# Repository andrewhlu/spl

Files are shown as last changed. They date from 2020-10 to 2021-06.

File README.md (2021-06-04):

<div class="center">
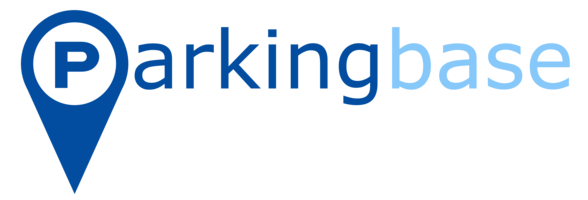
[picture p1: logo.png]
    
</div>

# Smart Parking Lot

A project for [ECE 189 - Computer Engineering Capstone](https://web.ece.ucsb.edu/~yoga/capstone/) led by Professor Isukapalli at UC Santa Barbara

---

[Parkingbase Demo Video](https://www.youtube.com/watch?v=abxjF7t0qpM)

[Parkingbase Poster](docs/poster.pdf)

---

## Team Members

* Andrew Lu
* Finn Linderman
* Luyao Han
* Seungjun Cho

## The Problem

Drivers spend too much time in parking lots trying to find an open space to park in. Many parking lots only have per-floor capacity indicators, and existing solutions are prohibitively expensive.

What if we could utilize low-cost sensors and a companion application to navigate drivers to empty parking spots faster, at a low cost to facility owners?

## Project Overview

**The goal of this project is to design a smart parking lot that will direct drivers to the nearest open parking space in an efficient, accurate, and clean manner.**

We accomplish this using:

* Small, inexpensive parking lot sensors with long-range and low-power transmission
* Modern, open-source, and cloud-based software solutions
* Easy-to-use mobile interfaces

# Technical Details

For a more detailed description, please take a look at our [project presentation slides](docs/final-presentation.pdf).

## System Overview

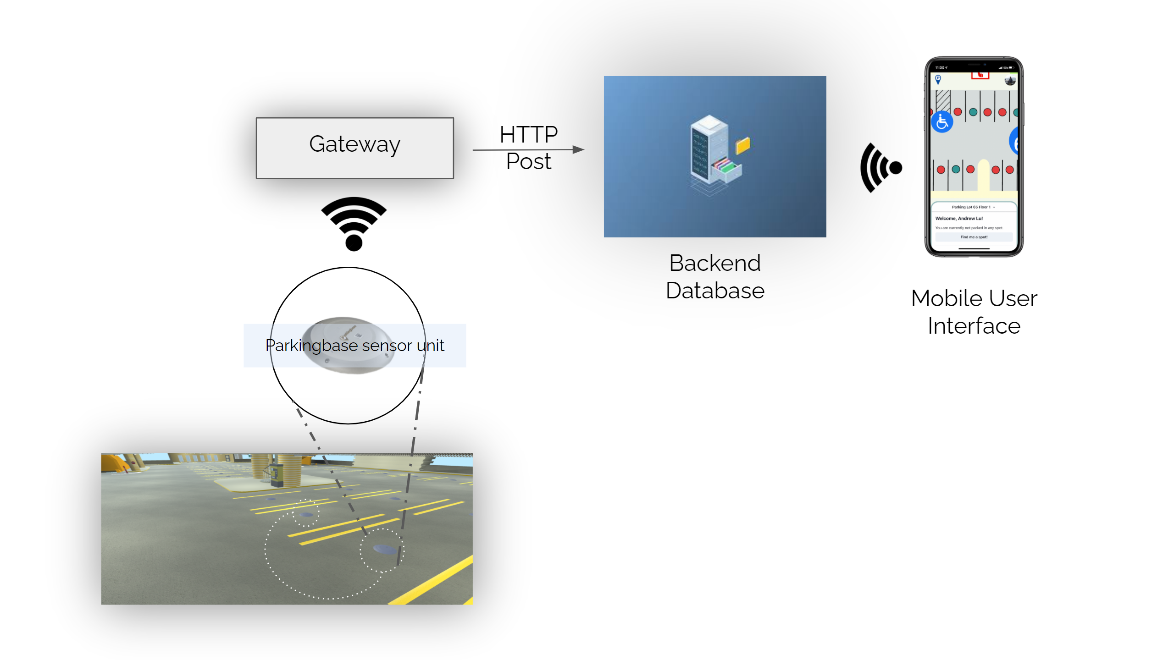
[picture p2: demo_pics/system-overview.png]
System Overview


## Application Scene

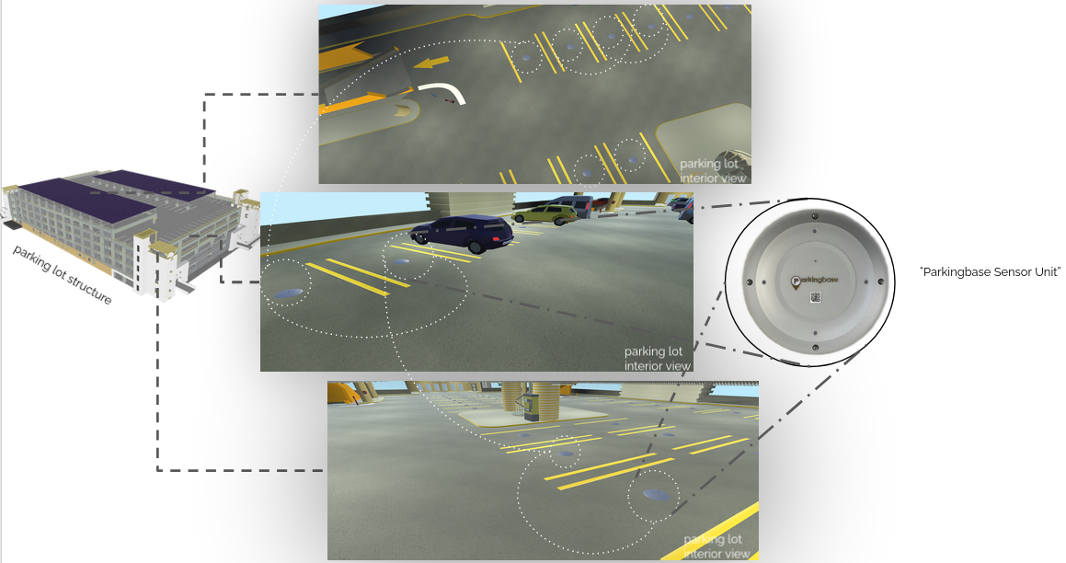
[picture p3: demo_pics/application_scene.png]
Application Scene


## Block Diagram

<div class="center">
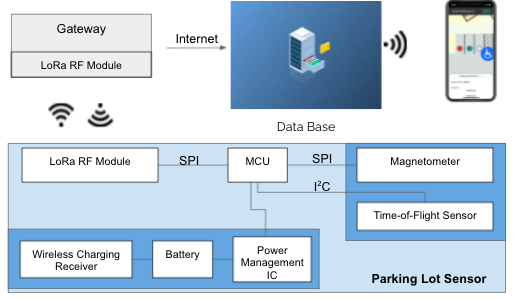
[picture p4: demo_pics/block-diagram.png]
  
</div>

## Sensor Unit Assembly

<div class="center">
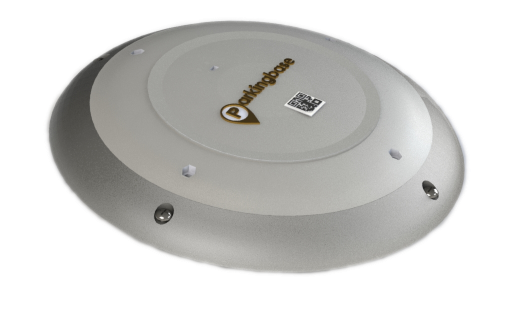
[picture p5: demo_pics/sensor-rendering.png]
  
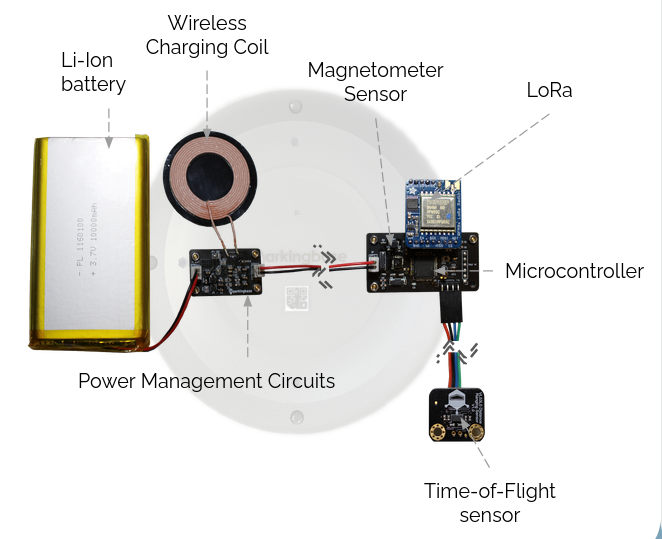
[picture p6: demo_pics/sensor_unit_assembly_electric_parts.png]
  
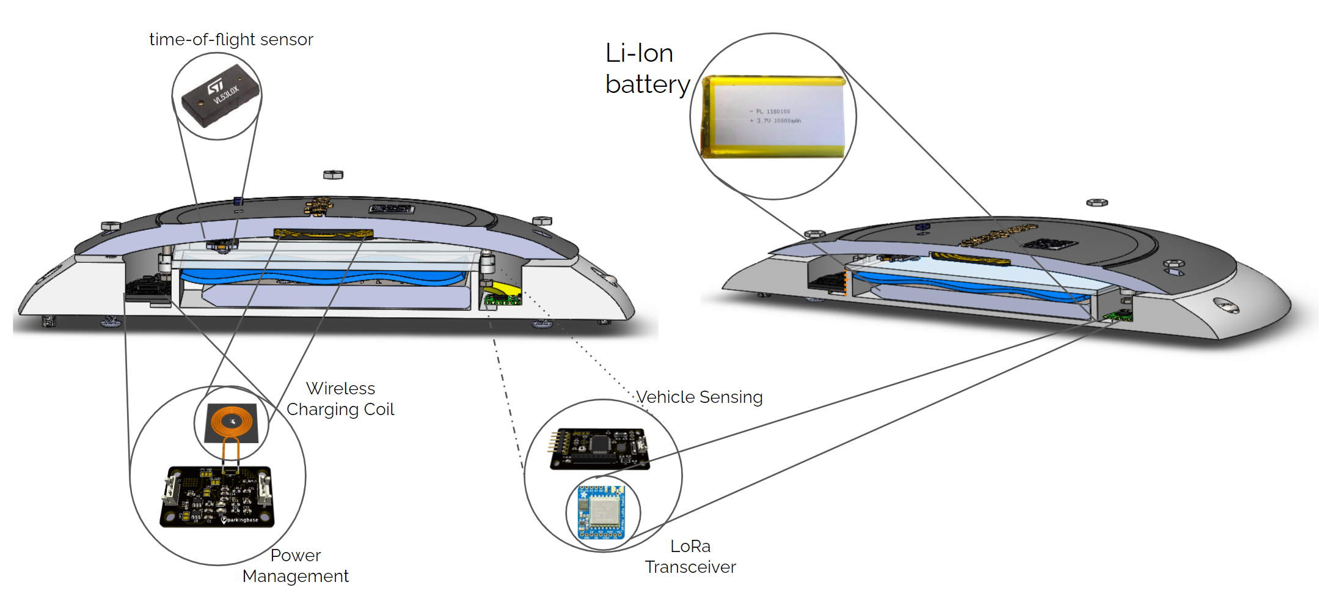
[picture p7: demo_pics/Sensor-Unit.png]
  
</div>

## Firmware Block Diagram

<div class="center">
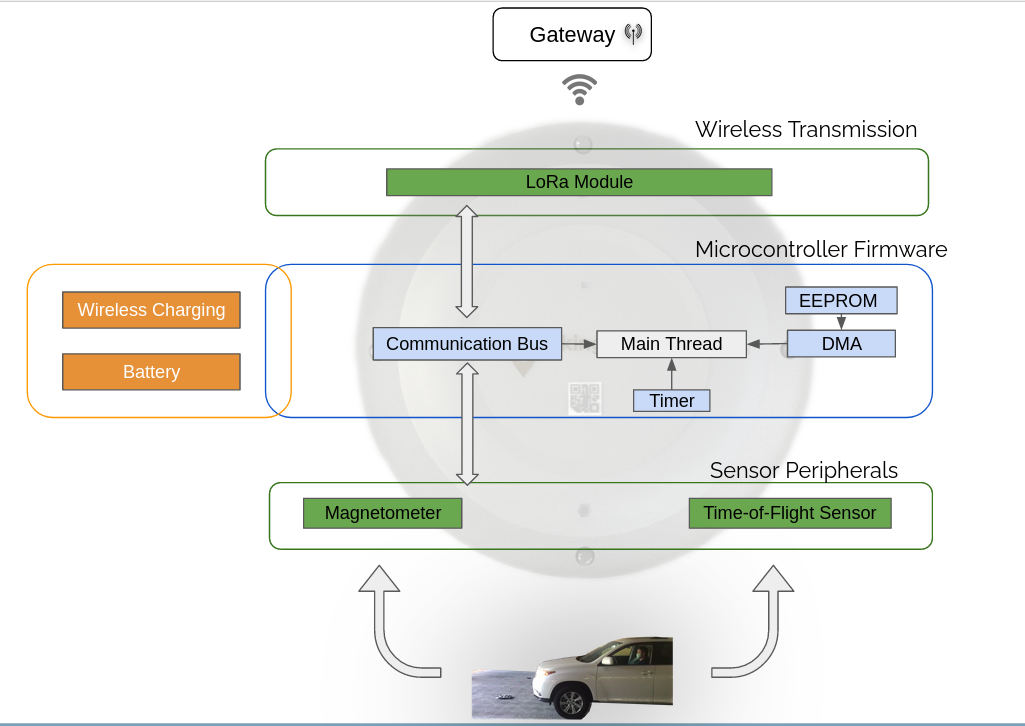
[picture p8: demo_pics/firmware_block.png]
  
</div>

## Sensor Unit PCB Design

The raw Kicad design files can be found in the [pcb-design folder](https://github.com/andrewhlu/spl/tree/main/pcb_design) in our repo.

[PCB Schematic (as PDF)](docs/sch.pdf)

[PCB Schematic (as PNG Image)](docs/sch.png)

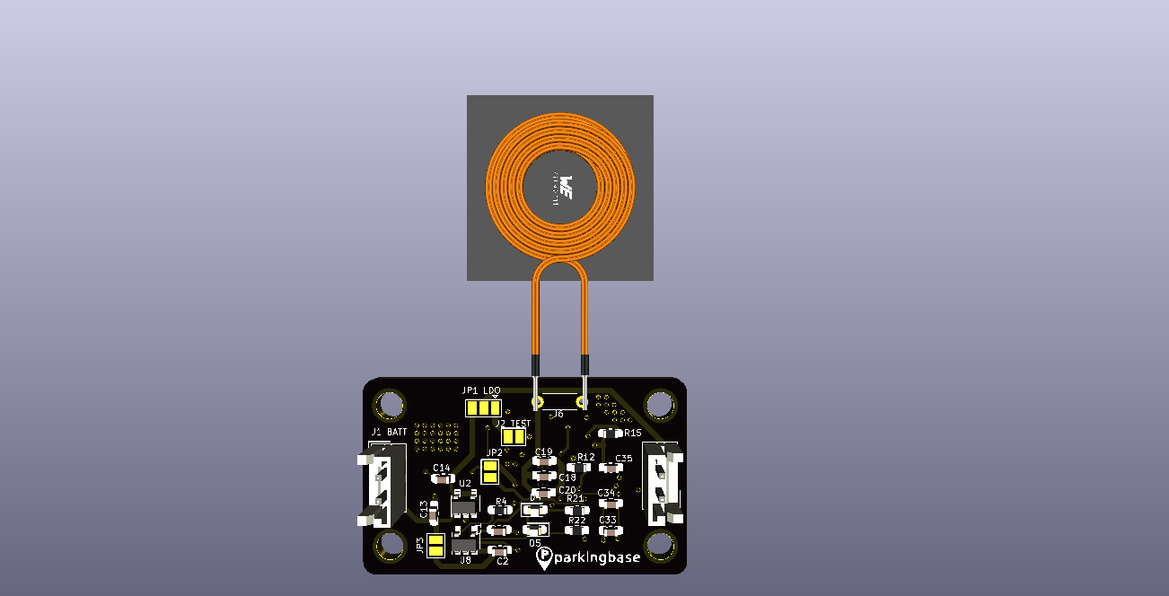
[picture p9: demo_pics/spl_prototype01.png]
Prototype


## GUI Screenshots

Driver User Interface:

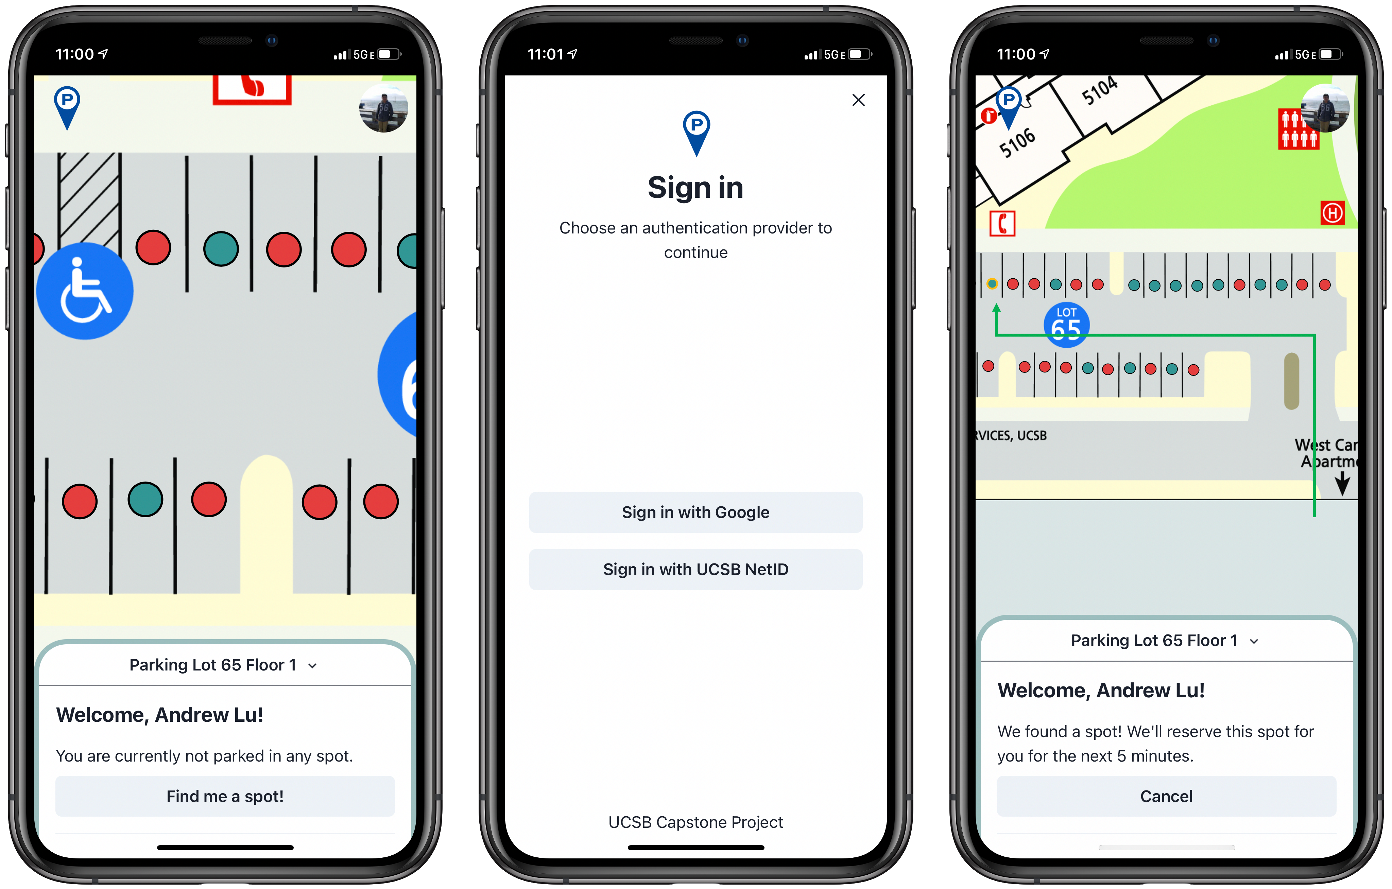
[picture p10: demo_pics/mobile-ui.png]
Mobile UI


Editor User Interface:

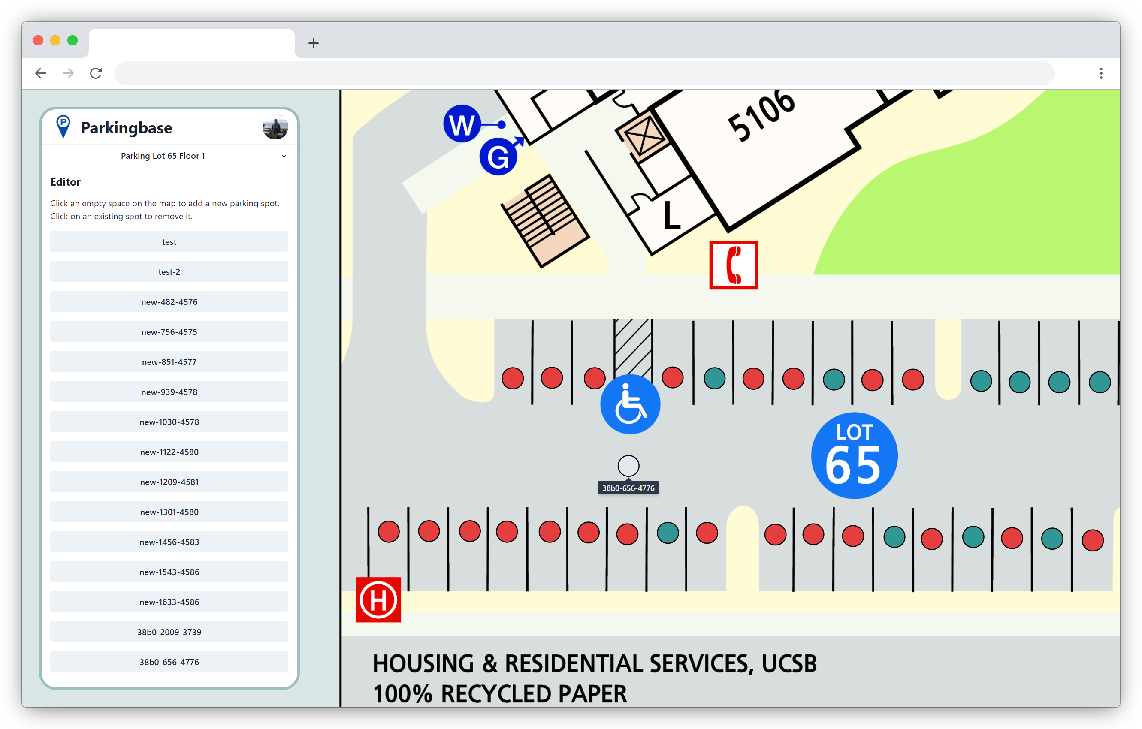
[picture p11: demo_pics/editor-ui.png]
Editor UI


## Code Repositories

* [spl](https://github.com/andrewhlu/spl)
  * Documentation for this website
  * PCB Design files
  * Demo pictures
* [spl-web](https://github.com/andrewhlu/spl-web)
  * Code for our website, including the React frontend and backend API routes
* [parkingbase-auth](https://github.com/andrewhlu/parkingbase-auth)
  * Code for our custom authentication server

# Project Progress Updates

[Initial Design](docs/initial-design.pdf)

[Milestone 1](docs/milestone1.pdf)

[Milestone 2](docs/milestone2.pdf)

[Fall Quarter Review Presentation](docs/fall-quarter-review.pdf)

[Winter Quarter Review Presentation](docs/winter-quarter-review.pdf)

[Final Poster](docs/poster.pdf)

[Final Presentation](docs/final-presentation.pdf)

<!-- Custom CSS for GitHub Pages -->

<style>
  .markdown-body h1:first-of-type {
    display: none;
  }

  .center {
    text-align: center;
    padding: 1rem;
  }
</style>

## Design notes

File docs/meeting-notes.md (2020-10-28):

# Smart Parking Lot - Team Meeting Notes

## 10/5 Meeting

We started this meeting by deciding on our team lead - Andrew Lu. 

We also decided on a scribe for our meetings - Kelly Yeh.

Resources compiled from individual research:

* [Bosch Parking Lot Sensor](https://www.bosch-connectivity.com/products/connected-mobility/parking-lot-sensor/)
  * A solution very similar (at least in appearance) to the one seen on JAPA. 
  * [Bosch Datasheet, Manuals](https://www.bosch-connectivity.com/products/connected-mobility/parking-lot-sensor/downloads/)
  * [Alliot (Vendor) Datasheet, Specs](https://www.alliot.co.uk/products/sensors/parking-management-sensors/bosch-lorawan-parking-sensor/)
    * This vendor sells for [£175.75 + VAT](https://www.alliot.co.uk/products/sensors/parking-management-sensors/bosch-lorawan-parking-sensor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) (which is roughly $227.2 excluding tax).
    * This is about 7.6% of our budget, so we don't think it's worth the investment to purchase for R&D.
* [2008 IEEE Paper from USC - "Intelligent Parling Lot Applications Using Wireless Sensor Networks"](http://anrg.usc.edu/~amitabhag/papers/CTS-2008.pdf)
* [Vehicle Detection Solutions - YouTube](https://www.youtube.com/watch?v=7a1fiUJtp_k)

Brief notes from our discussion of the various sensors:

Ultrasonic Sensor
- Generally very accurate when used to detect vehicles 
- Tradeoff between accuracy and power

Magnetometer
- Relatively low power consumption
- Complicated object detection algorithm
- May require heavy signal processing
- More resistant to noise

IR light
- Requires emitter + sensor combo (something on both sides)
- Measure light being emitted
- Can be used at night, but costly, and can only be used indoors

Action Items: 
- Clarify with Yoga regarding power consumption and usage/maintenance requirements in Parking lot 10 and which parking lots the project will be used for.
- Decide on overhead wired vs in-ground vehicle detection sensor
- Research and decide if solar power is an option

## 10/7 Meeting

Office hours with Yoga, Luyao, Andrew

Confirmed with Yoga: 
- wired devices are not accepted in parking lot
- cannot get a Park JAPA sensor from TPS

Suggested research topics:
- wireless transceiver device suited for average parking lot dimension
- low power consumption processor
  - Luyao will look into STM32L0
- solar panels as a method of extending battery life

Suggested device aspects:
- should last for at least 5 years

## 10/9 Meeting

We started by discussing our new project requirements from Office Hours

Problems with Battery-powered Solutions
- Wireless communication
  - This might require a lot of power, esp. to get past metal from cars and concrete slabs

Problems with Solar Panels
- Only works for outdoor parking structures without a roof (i.e. not Parking Lot 10)
- Where would we put the solar panel?
  - Putting it directly on the space would work, but we can't guarantee that there will be periods of time where there is no car parked and the unit can charge
- We are going to hold off on researching this for now - if we have time later, we can look into making a version with a solar panel (i.e. an "outdoor" model)

### Areas of Research for Next Week

Microprocessor / Magnetometer
- Luyao will look into purchasing a Nucleo dev board with an STM32L0 or L1 microprocessor and magnetometer
- Select a model over the weekend, get it reviewed briefly on Monday, then we can ask Yoga to get it expensed / procured
- We will start with a magnetometer-only solution for now, we will look into ultrasonic later (if needed)

Communication between Devices
- We want to look into pre-built communication modules instead of R&Ding our own solution
  - Will make PCB prototyping much easier
  - Matching impedance for antenna will be a challenge, not worth the time spent
  - May make power consumption issue worse though
- Potential protocols
  - Bluetooth LE
  - Zigbee
  - RFID
  - LoRaWAN / LPWAN
  - IEEE 802.11ah
- For each of these, what will we be researching?
  - Power consumption
  - Distance
  - Interference (by metal / concrete)
  - Cost
  - Scalability (number of devices)
- Potential idea: look into using hubs as a middleman between main gateway / server and parking spaces as a way to reduce power consumption

Luyao and Andrew will individually meet on Monday to discuss purchasing of dev board, otherwise we will likely not meet again as a team until Friday.

## 10/14 Meeting

This meeting was mostly a status update for Professor Yoga and the TAs. We presented our plans for researching communication modules, and finalized purchases for the dev board and magnetometer.

Action item for next meeting includes creating a chart comparing the various protocols and modules so we can start purchasing them. 

## 10/22 and 10/23 Meetings

This meeting started with some sad news - Kelly Yeh has left the group to pursue CS Capstone. We wish her well in her endeavors!

Earlier this week, we had agreed to limit our research to only LoRaWAN and Zigbee because these protocols were openly available and widely used, and were most suitable for our project due to range and power consumption. With the scope narrowed down, we spent our time researching various modules and compiled our findings into the following tables:

[SPL Parts Comparison](https://docs.google.com/presentation/d/1yRpL1xZ8KImvildn2UcqCzZ-FXLFVyuSgNTehhlwKwY/edit?usp=sharing)

Both technologies had their advantages and disadvantages, so we ultimately decided in Friday's meeting with Professor Yoga and the TAs that it would be beneficial to experiment with both. We discussed some of the modules we found, and made the decision to purchase a set of each andd test with it in the coming weeks.

Aside from compiling our research on communication modules, we spent the meeting compiling [Milestone 1](milestone1.pdf).

Action items for next week include procuring the LoRaWAN and Zigbee modules and dev boards, and testing our new magnetometer in one of the UCSB parking structures.

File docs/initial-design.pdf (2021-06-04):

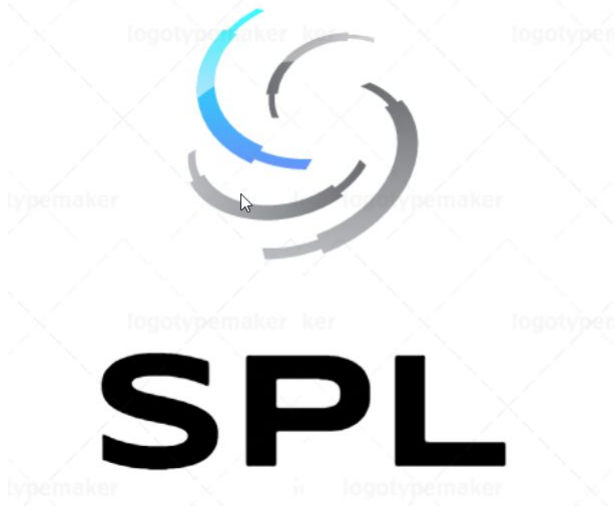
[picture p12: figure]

# Smart Parking Lot

## andrewhlu.com/spl

## Problem

Drivers spend too much time in parking lots trying to find an open space. Many parking lots only have per-floor capacity indicators, and existing solutions are prohibitively expensive.

What if we could utilize low-cost sensors and a companion application to navigate drivers to empty parking spots faster, at a low cost to facility owners?

## Solution

Our aim is to create a small, inexpensive wireless device that will be placed on each parking spot, capable of lasting five years on a single charge. Each device contains a vehicle-detecting sensor that can detect whether a car is parked in that particular spot. The devices are all connected using a low-power communication protocol to a central gateway device. This gateway device propagates sensor data to the Internet, which allows users to view parking spot availability through a mobile application or website.

## Roles

Short-term Responsibilities:
- Finn L. and Luyao H. - Vehicle detection sensor research
- Andrew L. and Jun C. - Communication module research

Long-term Responsibilities:
- Andrew L. - Parking Lot Terminal / Gateway
- Finn L. - Wireless Communication Firmware
- Luyao H. - Sensor Firmware / PCB Design / Power Management
- Jun C. - GUI / Path Finding Algorithm

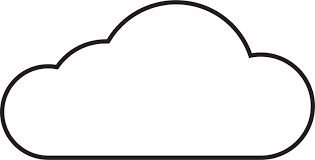
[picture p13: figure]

Terminal | GUI

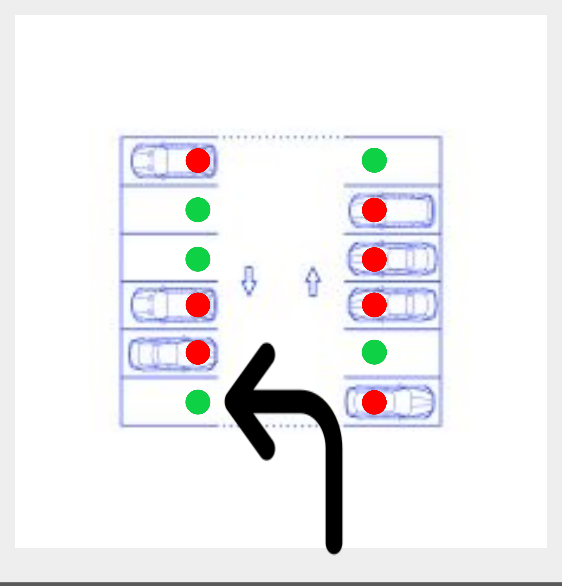
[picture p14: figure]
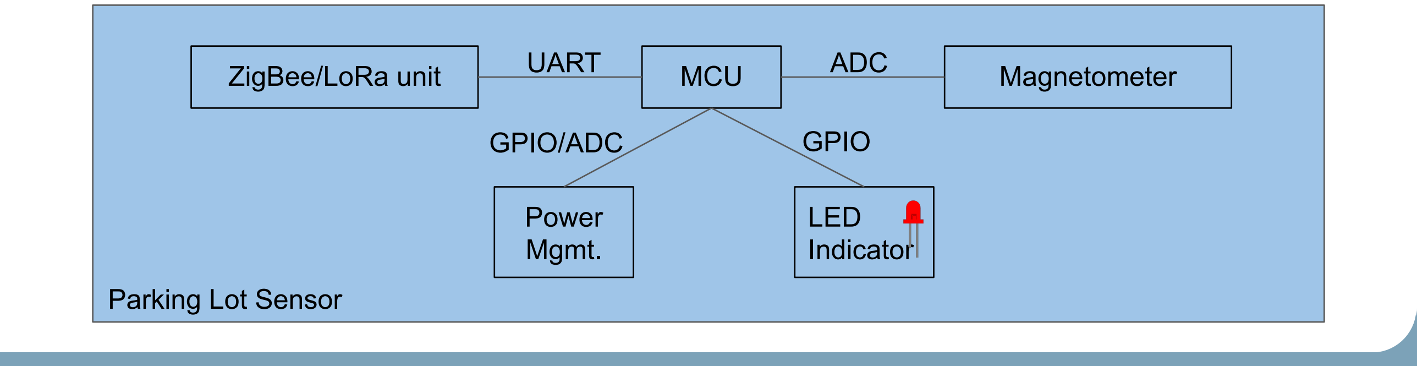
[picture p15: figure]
Power Mgmt.; GPIO/ADC; Parking Lot Sensor; LED Indicator; GPIO

ZigBee/LoRa unit | MCU | Magnetometer UART | ADC

ZigBee/LoRa unit

Internet

## Vehicle Detection Methods

- Sensing Technologies
- Magnetometer
- Ultrasonic
- Infrared
- Light Grid
- Magnetometer
- Magnetoresistive (inductive)
- Hall Effect
- Differential Hall Effect
- Sensor Attachment
- Power Consumption
- Maintenance

Max Sensing
Range
Size of Target | Mounting | Power Consumption | Environment Noise

Wireless
Magnetometer

Depends on the
size of target
All sizes | Can be installed above or below grade | comparatively low | Relatively stable

Wireless
Ultrasonic Sensor
4 meters | All sizes | Must be mounted overhead | Comparatively high | Relatively stable
Radar Sensor | <50 meters | Large,
predictable
targets (e.g.
trains)
Minimum of 6 feet from target | Need power outlet | Relatively stable

Optical Sensor
(Infrared)
<100 meters | 5 millimeters or
greater

Requires mounting for both emitter and receiver

Comparatively low | Sensitive to ambient light, sunlight

Measuring Light
Grid
<2 meters | All sizes | Requires mounting for both emitter and receiver
Need power outlet | Sensitive to ambient light, sunlight

Vehicle Detection Methods

Max Transmitting
Range

Frequency
(Potential
Interference)
Data Transmission Rate | Power Consumption | Part(s) Used for Testing
Zigbee | 10-100 meters | 2.4 GHz | 250kbps | 2.96 J | STM32WB55 Nucleo Pack
LoRaWAN | 2-15 kilometers | 433 MHz,
868 MHz,
915 MHz
0.3-50 kbps | 3.50 J | ESP32 LoRa 32 (V2) Development Board
STM32L053R8 Development Board NUCLEO-LRWAN1 Expansion Board
WiFi | 50 meters | 2.4 GHz,
5 GHz
150-200 Mbps | 5.00 J | N/A

Bluetooth Low
Energy (BLE)
50-150 meters | 2.4 GHz | 1 Mbps | 4.5 J | N/A

Communication Protocols / Modules

Due to concurrent device limitations, power consumption concerns, and transmission range, we are starting with the Zigbee and LoRaWAN communication standards.

## Power Management IC (PMIC)

LP3905
- -.2V to 6V range
- 0 to 600 mA range
- Used typically for low power handheld devices
- 2 Buck Regulator (DC2DC step down voltage/Step up current)
- 2 LDO (Low Dropout Regulator)
- No Recharge

## Schedule

Fall Quarter, Week 8 Finalize Initial Parts List Fall Quarter, Week 10 Initial Circuit Design Winter Quarter, Beginning Initial Prototype

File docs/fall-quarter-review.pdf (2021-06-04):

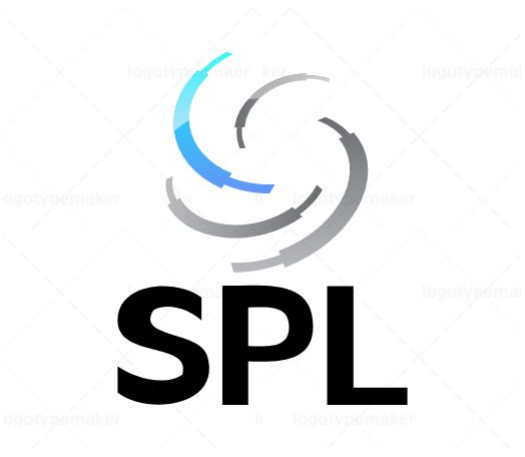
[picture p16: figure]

# Smart Parking Lot

Fall Quarter Review

## Problem

Drivers spend too much time in parking lots trying to find an open space. Many parking lots only have per-floor capacity indicators, and existing solutions are prohibitively expensive.

What if we could utilize low-cost sensors and a companion application to navigate drivers to empty parking spots faster, at a low cost to facility owners?

## Solution

- A small, inexpensive wireless device that will be placed on a parking spot
- Device can last five years on a single charge
- Device contains a vehicle-detecting sensor that can detect whether a car is parked in that particular spot
- Devices connected with low-power communication protocol to a central gateway device. Gateway device propagates sensor data to the Internet, which allows users to view parking spot availability through a mobile application or website.

## Roles

Short-term Responsibilities:
- Finn L. and Luyao H. - Vehicle detection sensor research
- Andrew L. and Jun C. - Communication module research

Long-term Responsibilities:
- Andrew L. - Parking Lot Terminal / Gateway
- Finn L. - Wireless Communication/ Power Management
- Luyao H. - Sensor Firmware / PCB Design/ Wireless Charging
- Jun C. - GUI / Path Finding Algorithm

Microcontroller Selection
STM32L053r8 | ST Ultra-low power product line
Power consumption - low power consumption - 88 µA/MHz in Run mode - 0.27 µA Standby mode

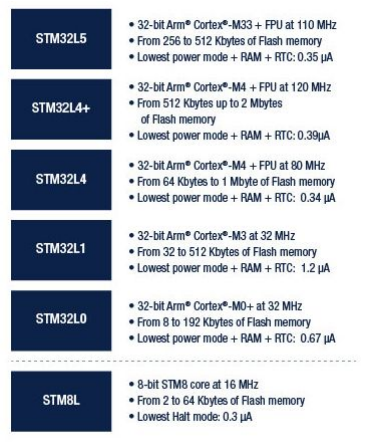
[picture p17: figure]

Peripherals
- SPI/I2C/USART
- EEPROM for storing device ID Firmware Development
- Nucleo
Packaging
- QFP64

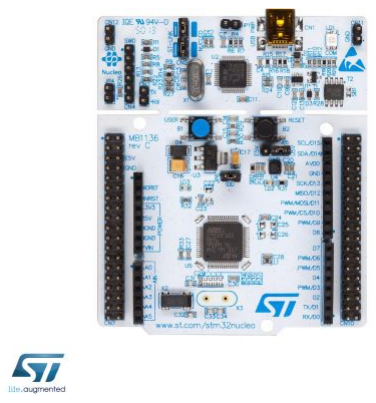
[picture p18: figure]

## Vehicle Detection Sensors

- Main Factors to consider
- Power Consumption
- Installation
- Lifespan of component
- Sensing Technologies
- Magnetometer
■ Magnetoresistive (inductive) ■ Hall Effect
■ Differential Hall Effect
- Ultrasonic
- Infrared
- Light Grid

Max
Sensing
Range

Size of
Target

Power consumption
(average current)
Environment Noise | Lifespan

Wireless
Magnetometer

Depends on
the size of
target
All sizes | < 1 mA | Ambient Magnetic Field | < 20 years

Wireless
Ultrasonic
Sensor
4 meters | All sizes | > 5 mA | Dust, Tangible Particles | < 20 years
Radar Sensor | <50 meters | Large,
predictable
targets
(e.g.
trains)
> 50 mA | Relatively stable | < 6 years

Optical
Sensor
(Infrared)

<100 meters 5
millimeters
or greater
> 20 mA | Sensitive to ambient light, sunlight | 2~8 years

Measuring
Light Grid
<2 meters | All sizes | > 200 mA | Sensitive to ambient light, sunlight | unknown

Vehicle Detection Sensors - A Closer Look

Vehicle Detection Sensors - Experiment Setup

Sensor | Mechanism | Result
LM351LT | Hall Effect | Failure
TLE4921 | Differential Hall Effect | Failure
RM3100 | Magneto-Inductive | Success
HC-SR06 | Ultrasonic Sensor | Success

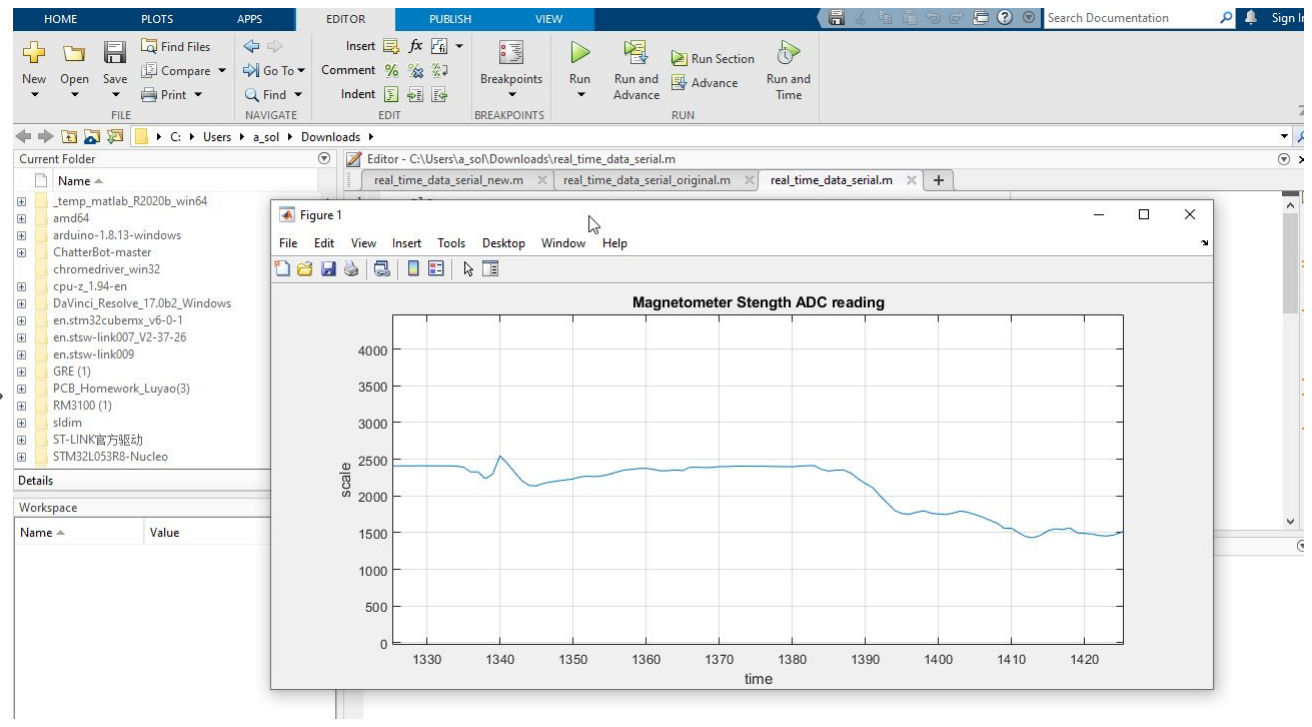
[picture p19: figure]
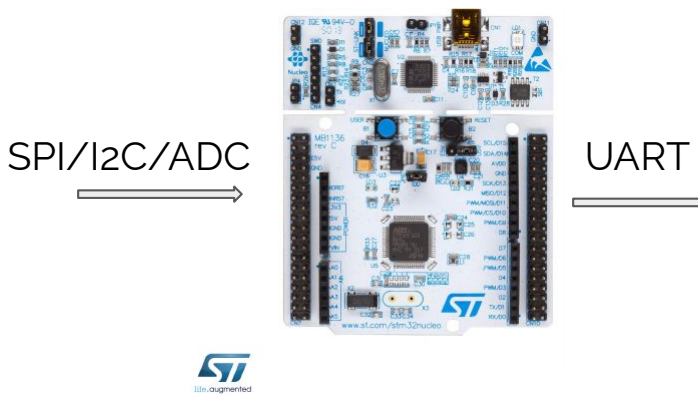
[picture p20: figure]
SPI/I2C/ADC; UART

Vehicle Detection Sensors - Experiment in Parking Lot 22

Wireless charging

Deployable Wireless Charger
Charging
- Domed shaped unit attached to top of sensor unit Estimation
- 5 years ~= 45000 hours
- calculated power consumption 0.22 mA
- Charging 2.5 hour with 15W charger Advantage
- Sensor still operable when charging
- Convenience for maintenance Disadvantage
- Distortion to sensitivity of magnetic sensor
- Could be stolen

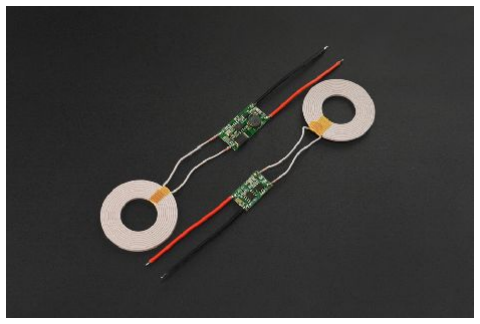
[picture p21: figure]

## Communication

- Low Power Consumption
- Must support high number of concurrent devices
- Range from sensor to gateway
- Data rate negligible
- Robustness to interference
- Availability & cost

Max Transmitting
Range

Frequency
(Potential
Interference)
Data Transmission Rate | Power Consumption | Part(s) Used for Testing
Zigbee | 10-100 meters | 2.4 GHz | 250kbps | 2.96 J | STM32WB55 Nucleo Pack
LoRaWAN | 2-15 kilometers | 433 MHz,
868 MHz,
915 MHz
0.3-50 kbps | 3.50 J | STM32 I-NUCLEO-LRWAN1 Expansion Board
Heltec ESP32 LoRa 32 (V2) Development Board
WiFi | 50 meters | 2.4 GHz,
5 GHz
150-200 Mbps | 5.00 J | N/A

Bluetooth Low
Energy (BLE)
50-150 meters | 2.4 GHz | 1 Mbps | 4.5 J | N/A

Communication Protocols / Modules

Due to concurrent device limitations, power consumption concerns, and transmission range, we are starting with the Zigbee and LoRaWAN communication standards.

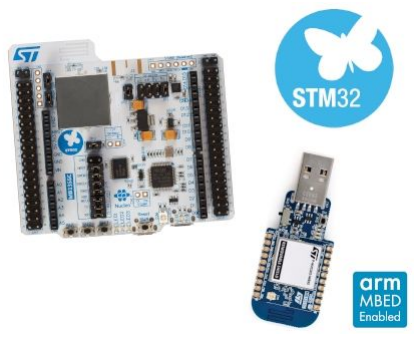
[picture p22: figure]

STM32WB55 Nucleo Pack
- Nucleo68 uses STM32WB55RG
- USB Dongle uses STM32WB55CG
- Both support IEEE 802.15.4 / Zigbee 3.0

STM32WB55 Series MCUs
- Based on Arm Cortex M4
- Up to +6 dBm transmission power
- -100 dBm receiver sensitivity
- 1.7V to 3.6V input voltage range
- 600 nA in standby, 5.2 mA when transmitting

## Zigbee

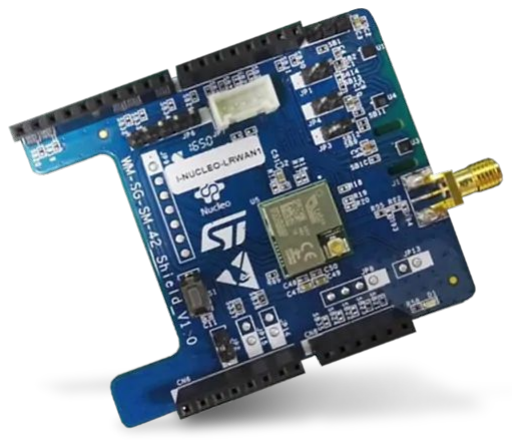
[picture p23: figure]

STM32 I-NUCLEO-LRWAN1
- Semtech SX1272
- 860 MHz to 1020 MHz frequency range
- 14 dBm to 20 dBm transmission power
- -137 dBm receiver sensitivity
- 2.0V to 3.6V voltage range
Heltec ESP32 LoRa 32 (V2)
- Semtech SX1276
- 868 MHz to 915 MHz frequency range
- 15.5 dBm to 19.5 dBm transmission power
- -139 dBm receiver sensitivity
- 3.3V to 7V voltage range

## LoRa/LoRaWAN

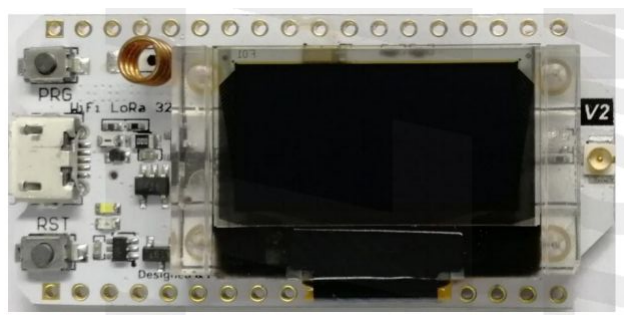
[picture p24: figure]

## Battery

- Battery needs a minimum of 5 year life
- Current power consumption ~150mA
- Maximum batter with suitable dimensions is 10Ah
- Must cut power consumption by a degree of 100
- Transmitter is the most costly hardware
- Sensor / processor power consumption are minimal (micro amps)
- Transmit every 30 seconds

## Power Management IC (PMIC)

LP3905
- -.2V to 6V range
- 0 to 600 mA range
- Used typically for low power handheld devices
- 2 Buck Regulator (DC2DC step down voltage/Step up current)
- 2 LDO (Low Dropout Regulator)
- No Recharge
- Need a second PMIC specifically for charging


Terminal | GUI

Power Mgmt.; GPIO/ADC; Parking Lot Sensor; LED Indicator; GPIO

ZigBee/LoRa unit | MCU | Magnetometer UART | ADC

ZigBee/LoRa unit

Internet

## Schedule: Fall Quarter

Fall Quarter, Week 8
Finalize Initial Parts Testing
Fall Quarter, Week 9-10
Prototyping PCB for individual sensor units
- power management
- wireless communication units
- various sensor and test ports
- wireless charging receiver
- communication bus ports
Updating and development of firmware Winter Break
Receiving manufactured PCB for assembly

## Schedule: Winter Quarter

Winter Quarter, Week 1~2
Developing gateway data collection software Revision of sensor unit PCB, part selection Winter Quarter Week 2-5
Prototyping wireless charging transmitter Developing Android app prototype
- displaying parking vacancy
- pathfinding algorithm
Winter Quarter Week 6-9
Deploying large amount of sensor units to Parking Lot 10 for field test

## Schedule: Spring Quarter

Spring Quarter, Week 1~2
Mechanical case design
Spring Quarter, Week 3
*Final Product*
Spring Quarter, Week 3-8
Power consumption optimization Firmware design optimization
Battery charging efficiency optimization Android App User Experience Survey Market Value Survey
Spring Quarter, Week 9
Documentation

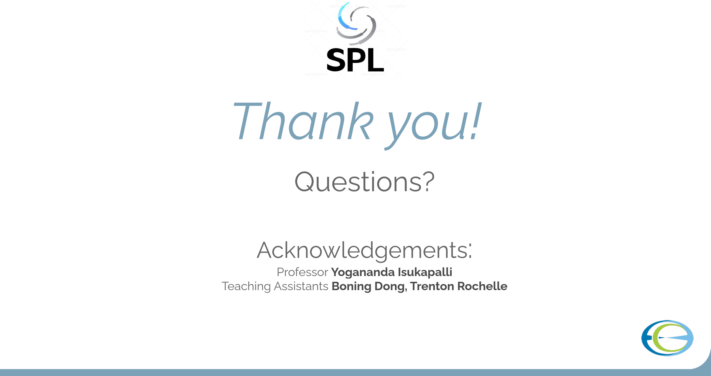
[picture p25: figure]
Thank you!; Questions?; Acknowledgements:; Professor Yogananda Isukapalli

Teaching Assistants Boning Dong, Trenton Rochelle

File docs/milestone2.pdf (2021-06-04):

## Smart Parking Lot

Milestone 2
Andrew Lu, Finn Linderman, Luyao Han, Seungjun Cho

Specification

Our project is to prototype an autonomous platform used to navigate drivers to parking spot vacancies.

A. The driver will access available parking space information through a graphical user interface, ideally programmed to an app, or alternatively, a web page.
a. When the driver arrives at the entrance, they will push the “Search for Space” button. The driver may be required to enter the floor they are interested in.
b. The GUI will then present occupancy information of the entire floor using a sketch with all the parking spaces on that floor.
c. The occupied spots are marked red, and the available spots are marked green.
d. The driver will drive to the available spot and park the vehicle. No more interaction with the GUI is needed.
e. (tentative) if the entire floor is rather huge and involves a lot of parking spaces, the GUI will actively direct the driver to the parking space by providing the shortest path with waypoints on the floor sketch.
B. The graphical user interface is actively updated, representing parking occupancy information received from a backend host.
a. Parking Lot staff can utilize the GUI to overwrite occupancy information, allowing parking spots to be temporarily marked as “occupied” for maintenance.
C. The host communicates with the entire mesh network of sensors. Each sensor records either a vehicle’s arrival or a vehicle’s departure to the single parking space the sensor is located at. Upon each successful detection, a change of state will be transmitted to the host.
a. Sensors will be installed in the ground.
b. The host receives updates from each sensor in passive mode in daily usage.
c. Parking Lot staff may request diagnostics from sensors, such as battery usage, daily count, functionality health check, and guidance light.

Block Diagram

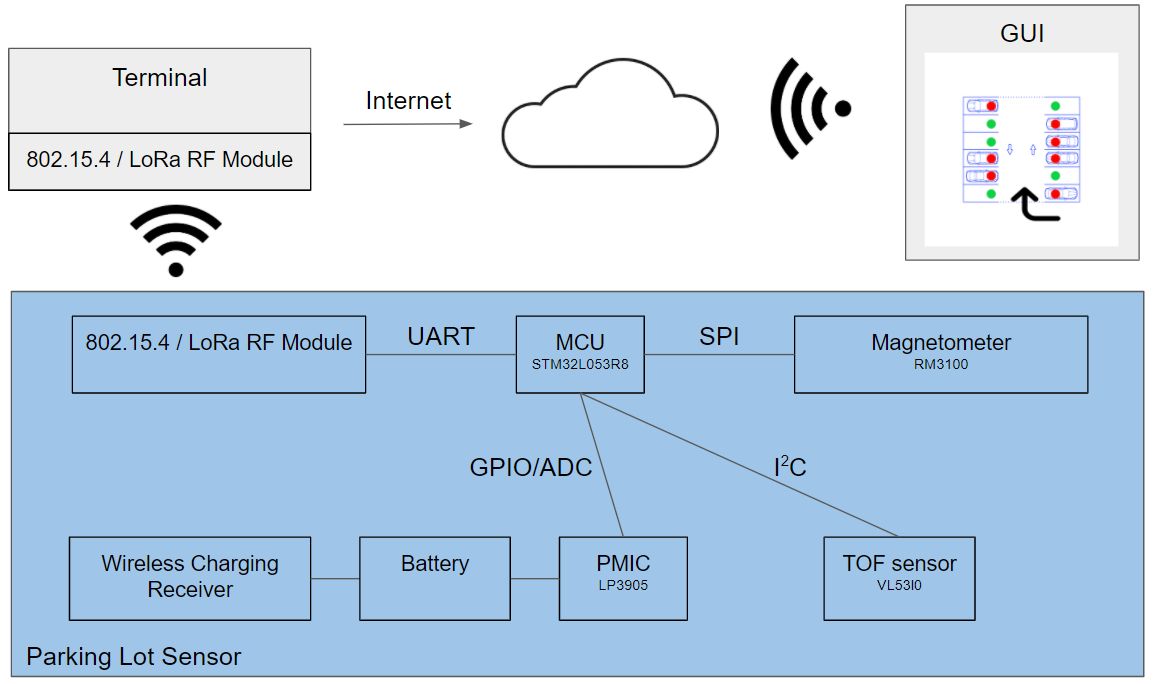
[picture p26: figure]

Member Responsibilities

These will be the long-term responsibilities for each member:

- Andrew Lu - Parking Lot Terminal / Gateway
- Finn Linderman - Wireless Communication Firmware
- Luyao Han - Sensors / Sensor Firmware / PCB Design / Power Management
- Seungjun Cho - GUI / Path Finding Algorithms

Since we are still in the early stages of development, and since the group is split in terms of location, these are the short-term responsibilities:

- Finn Linderman and Luyao Han
- Vehicle detection sensor research (i.e. Magnetometer)
- PCB creation
- Andrew Lu and Seungjun Cho
- Communication module research (i.e. LoRa vs. Zigbee)

Software Flow

- Parking Lot Sensor
- Every 30 seconds, the parking lot sensor will use the magnetometer and time-of-flight sensor to detect the presence of a vehicle.
- The parking lot sensor will report this to the floor’s gateway using ZigBee or LoRa
- When sending messages to the gateway / terminal application, the device will send its unique identifier, space status, and device health information.
- This will be implemented using low-level C
- Gateway / Terminal Application
- This device has a Zigbee or LoRa receiver that will accept all the incoming packets for devices on that floor.
- When a packet is received, the module will communicate that to a small computer (like a Raspberry Pi) over a UART signal. The device will then propagate that information to an online database.
- This will likely be implemented using a higher level programming language such as Python or JavaScript
- User Application
- The user application reads the online database and converts the information from the devices into a user-interactable graphical interface.
- This will take the form of either an Android app (Java) or a webpage (JavaScript / HTML).

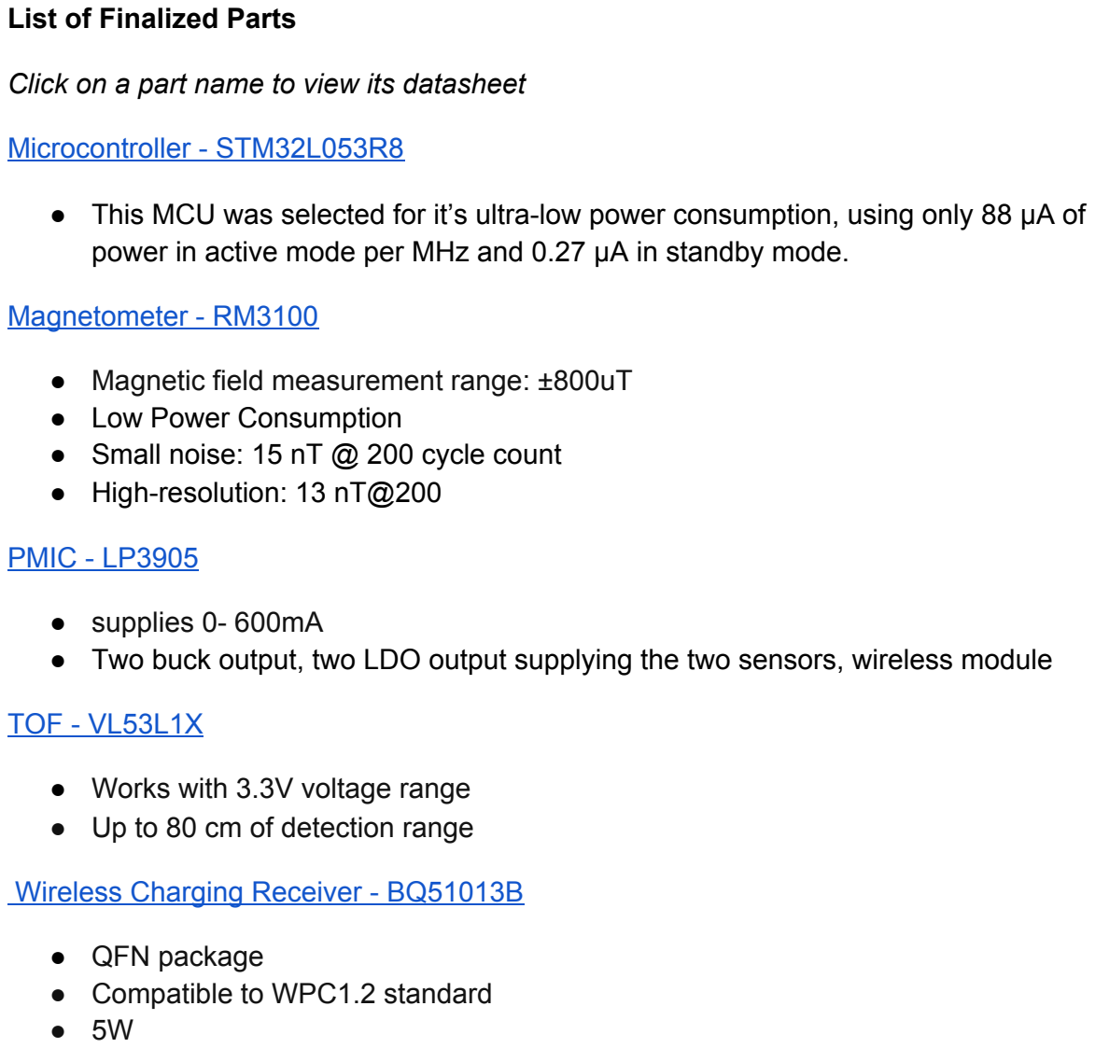
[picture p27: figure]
List of Finalized Parts; Microcontroller - STM32L053R8; Magnetometer - RM3100; ● Low Power Consumption ● Small noise: 15 nT @ 200 cycle count ● High-resolution: 13 nT@200; PMIC - LP3905; ● supplies 0- 600mA; TOF - VL53L1X; ● Works with 3.3V voltage range ● Up to 80 cm of detection range; Wireless Charging Receiver - BQ51013B; ● QFN package ● Compatible to WPC1.2 standard ● 5W

Click on a part name to view its datasheet

- This MCU was selected for it’s ultra-low power consumption, using only 88 µA of power in active mode per MHz and 0.27 µA in standby mode.
- Magnetic field measurement range: ±800uT
- Two buck output, two LDO output supplying the two sensors, wireless module

List of Tentative Parts

Click on a part name to view its datasheet

LoRa Radio - Adafruit RFM95W (https://learn.adafruit.com/adafruit-rfm69hcw-and-rfm96-rfm95-rfm98-lora-packet-padio-breakouts/downloads)

- Works with 3.3V and 5V voltage range
- Approximately 2 km transmission radius.
- Operates on the 915 MHz band in compliance with American license free ISM bands
- +5 to +20 dBm transmission power
- Average peak 100 mA power consumption during transmission at +20 dBm
- Average ~30 mA power consumption during active listening.
- $25 including antenna and external antenna connector.

802.15.4 (Zigbee) RF Module - XBee (https://www.digi.com/resources/library/data-sheets/ds_xbee-3-zigbee-3)

- Will be used in the parking lot sensor if choosing the Zigbee stack
- RF communication module capable of transmitting on the 2.4 GHz band according to the 802.15.4 network stack using the Zigbee protocol
- Communicates with the MCU with either UART, SPI, I²C
- +8 dBm transmitting power
- 40 mA power consumption when active
- 2 µA power consumption when inactive
- $25 including antenna

MB1293C Development Board (https://www.st.com/resource/en/data_brief/p-nucleo-wb55.pdf) (STM32WB55) (https://www.st.com/resource/en/datasheet/stm32wb55cc.pdf)

- Will be used in the terminal / gateway if choosing the Zigbee stack
- USB Dongle with STM32WB55CGU6 MCU
- Includes wireless coprocessor and onboard PCB antenna
- Full-size USB-A Male port that is used for programming and UART communication with another host device (likely to be a small computer)

List of Accomplishments for Fall Quarter

- Hardware
- Microcontroller
■ Firmware and I/O assignment specific for peripherals
- Established the method of vehicle detection
■ We originally compared magnetometer, hall effect, ultrasonic, infrared, and time-of-flight sensors.
■ Field test magnetometer with a vehicle
■ Magnetometer + Time of Flight
- Established power management features
■ Due to size and power constraints, we may not be able to achieve our initial planned 5-10 years of battery life.
■ However, to mitigate this concern, we are looking into the use of wireless charging
■ We also have a dedicated PMIC
- Research on Communication Modules
■ We initially researched all suitable methods of communication that could fit our needs (including WiFi, Zigbee, LoRa, and BLE), but settled on LoRa and Zigbee for low power consumption.
■ LoRa
- Extremely long range while consuming low power, thanks to using a lower bandwidth.
- The shorter bandwidth makes transmission of larger packets less efficient.
- However, this long range has the potential to cause problems with packet loss.
■ Zigbee
- Much shorter range and more susceptible to interference, given that the 2.4 GHz band is commonly used.
- However, protocol allows devices to be meshed together, reducing the need for long transmission ranges and therefore reducing interference between parking lot sensors.
- Software
- Firmware written for the microcontroller
- Since we are prioritizing hardware for now, we have not made progress on a user GUI

Plan for Winter Quarter

Weeks 1-2: PCB Verification / Final Decision on Transmission and Communication Hardware

The PCB will be manufactured during the winter break. The first step after winter break is to do PCB verification. Depending on verification, the schedule for the quarter will be dictated. The transmitter, PMIC and sensor will all be tested, and checked to see if they are able to communicate amongst each other. Lastly, the research for Zigbee meshing will be completed over the break, so we can move forward with the design.

Weeks 2-5: Rework Firmware, Define Message Protocol

After the PCB verification is finished, our firmware will need to be reworked. We also need to standardize our transmission protocols in order to make sure that there is no interference, and the information that is being transmitted is accurate. On the software side, we will start to define the message structure for transmissions between the parking lot devices and gateway, as well as the database structure for storing sensor data.

Week 6+: Start Software

After the PCB and firmware have been finished, we can actually begin to write the software for the parking algorithm and GUI. We will first start by creating a GUI for displaying the available parking spaces and testing to ensure robustness once it is scaled up. Once this is complete, we can start building the path finding algorithm for navigating drivers to empty parking spaces using the app.

Week 8+: Extensive Testing in Parking Lot

Once all of the above is complete, we will do extensive testing in an actual parking structure, likely UCSB’s Parking Lot 10.

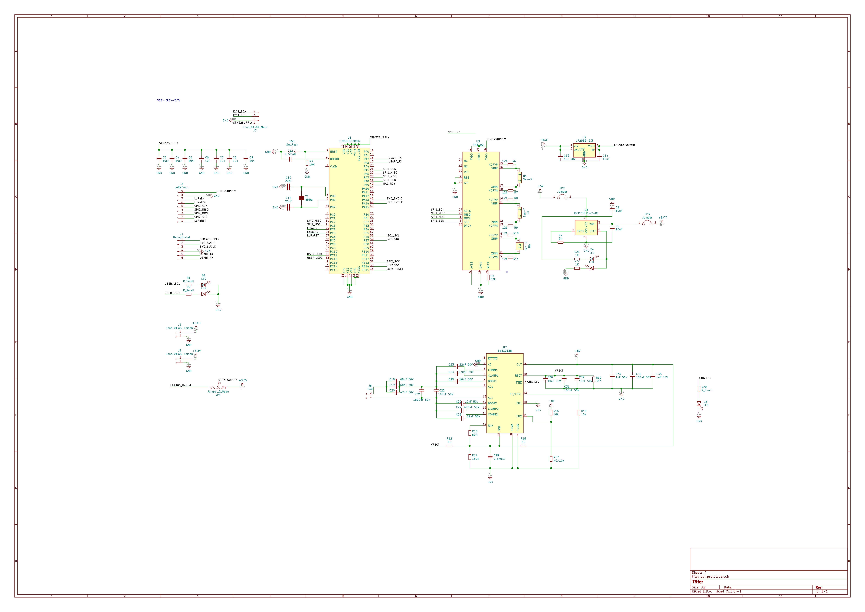
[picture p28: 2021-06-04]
docs/sch.png

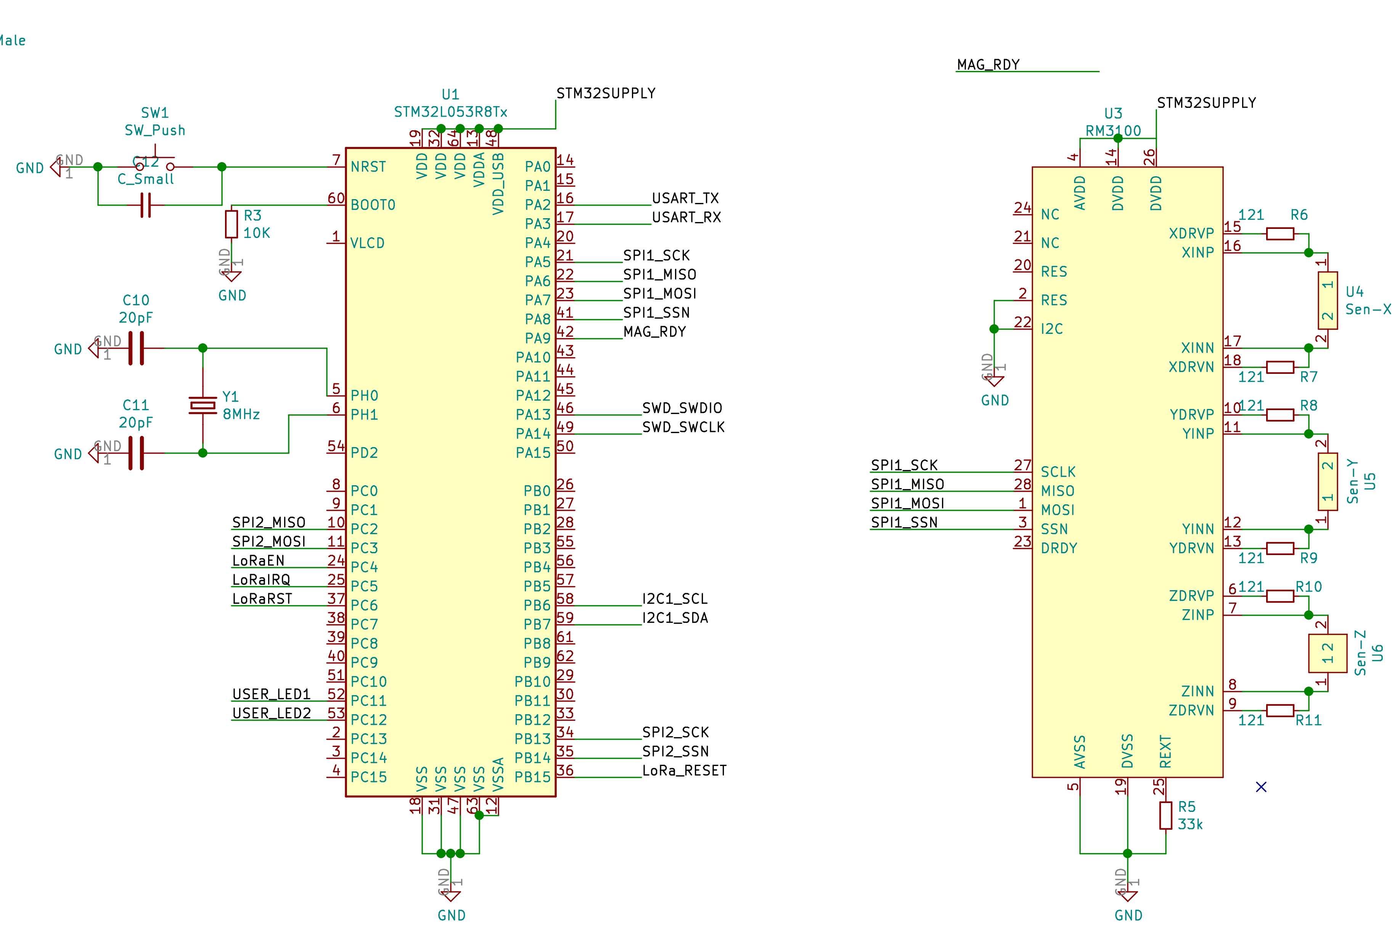
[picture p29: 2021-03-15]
demo_pics/MCU.png

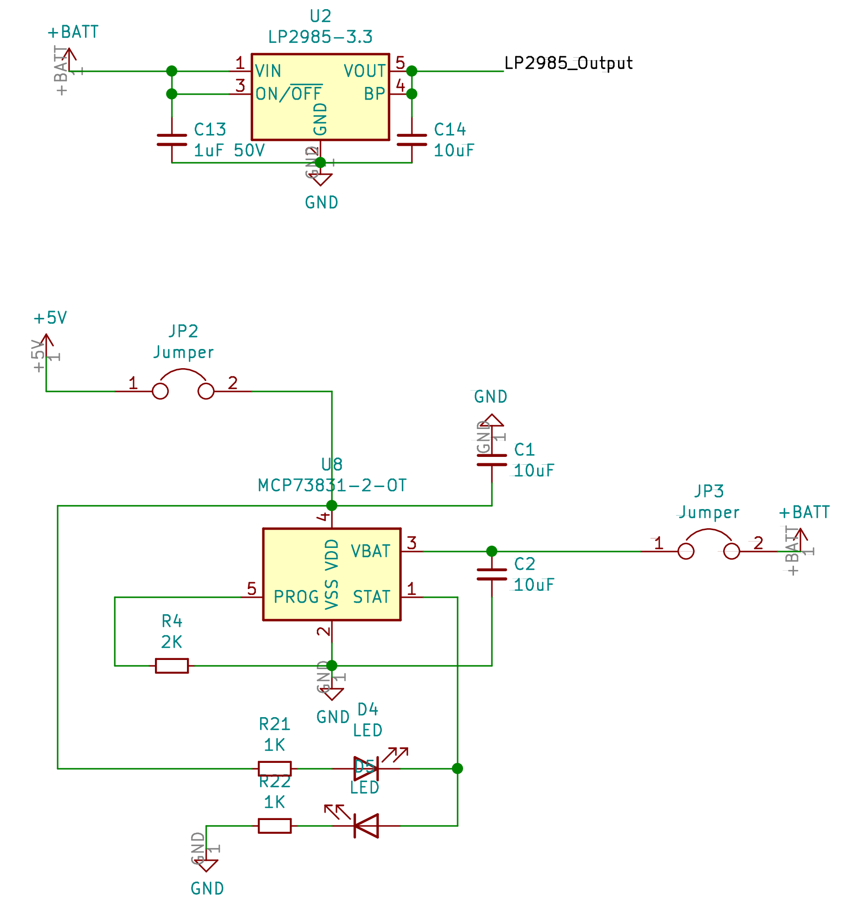
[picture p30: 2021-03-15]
demo_pics/power.png

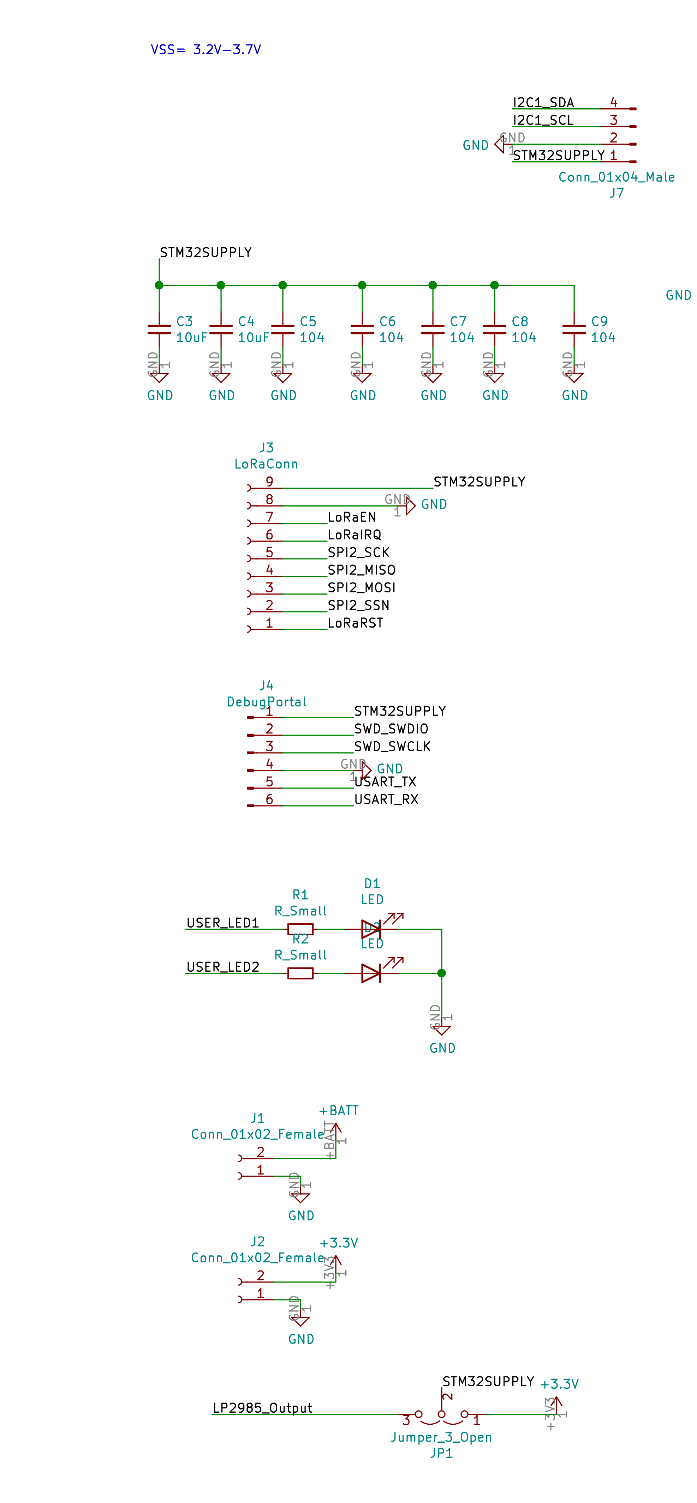
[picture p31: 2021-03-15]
demo_pics/pins.png

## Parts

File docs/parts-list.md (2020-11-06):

# Smart Parking Lot - Parts List / Budget Sheet

## Budget

For this project, we were given an initial budget of $3000.

The following table tracks our budget. You can click on an order (or scroll down) to view that order's parts list.

| Order | Price | New Balance | Status |
|---|---|---|---|
| Original Balance | | $3000.00 | |
| [10/16 Digikey Order](#1016-digikey-order) | $63.72 | $2936.28 | Received |
| [10/21 Amazon Order](#1021-amazon-order) | $40.84 | $2895.44 | Received |
| [LoRaWAN Mouser Order](#lorawan-mouser-order) | $54.47 | $2840.97 | Received |
| [LoRaWAN Amazon Order](#lorawan-amazon-order) | $27.36 | $2813.61 | Received |
| [Zigbee Digikey Order](#zigbee-digikey-order) | $47.36 | $2766.25 | Received |
| [Zigbee Amazon Order](#zigbee-amazon-order) | $14.64 | $2751.61 | Received |

---

## 10/16 Digikey Order

Placed by Luyao, Shipped to ECE Shop

[Link to Digikey Cart](https://www.digikey.com/short/zn4rj8)

| Part | Quantity | Unit Price | Total Price |
|---|---|---|---|
| [Nucleo-64 STM32L053R8 Development Board](https://www.digikey.com/short/zd3md2) | 3 | $13.83 | $41.49 |
| [Honeywell SM351LT Hall Effect Switch](https://www.digikey.com/short/zd3mvn) | 3 | $0.81 | $2.43 |
| [TLE4921 Differential Hall Effect Sensor](https://www.digikey.com/short/zd3m1h) | 3 | $2.90 | $8.70 |
| [HE515 Biasing Magnet](https://www.digikey.com/short/zd3h77) | 1 | $6.52 | $6.52 |
| Tax | 1 | $4.58 | $4.58 |
| **TOTAL** | | | **$63.72** |

## 10/21 Amazon Order

Placed by Andrew, Shipped to ECE Shop

| Part | Quantity | Unit Price | Total Price |
|---|---|---|---|
| [PNI RM3100 Magnetometer](https://www.amazon.com/dp/B01N5QL0XC/) | 1 | $37.90 | $37.90 |
| Tax | 1 | $2.94 | $2.94 |
| **TOTAL** | | | **$40.84** |

## LoRaWAN Mouser Order

Placed by Jun, Shipped to Jun

This order is being placed through Mouser because Digikey does not have any stock of the LoRa expansion board

| Part | Quantity | Unit Price | Total Price |
|---|---|---|---|
| [Nucleo-64 STM32L053R8 Development Board](https://www.mouser.com/ProductDetail/511-NUCLEO-L053R8) | 1 | $13.55 | $13.55 |
| [511-I-NUCLEO-LRWAN1 LoRa Expansion Board](https://www.mouser.com/ProductDetail/511-I-NUCLEO-LRWAN1) | 1 | $28.90 | $28.90 |
| UPS Ground Shipping | 1 | $7.99 | $7.99 |
| Tax | 1 | $4.03 | $4.03 |
| **TOTAL** | | | **$54.47** |

## LoRaWAN Amazon Order

Placed by Jun, Shipped to Jun

| Part | Quantity | Unit Price | Total Price |
|---|---|---|---|
| [ESP32 LoRa Development Board](https://www.amazon.com/dp/B076MSLFC9/) | 1 | $24.99 | $24.99 |
| Tax | 1 | $2.37 | $2.37 |
| **TOTAL** | | | **$27.36** |

## Zigbee Digikey Order

Placed by Andrew, Shipped to Andrew

| Part | Quantity | Unit Price | Total Price |
|---|---|---|---|
| [Nucleo-68 STM32WB55 BLE Development Pack](https://www.digikey.com/short/zn0tj4) | 1 | $43.75 | $43.75 |
| Tax | 1 | $3.61 | $3.61 |
| **TOTAL** | | | **$47.36** |

## Zigbee Amazon Order

Placed by Andrew, Shipped to Andrew

| Part | Quantity | Unit Price | Total Price |
|---|---|---|---|
| [Comidox CC2531 Zigbee USB Dongle](https://www.amazon.com/dp/B07KW1N1MR/) | 1 | $13.59 | $13.59 |
| Tax | 1 | $1.05 | $1.05 |
| **TOTAL** | | | **$14.64** |

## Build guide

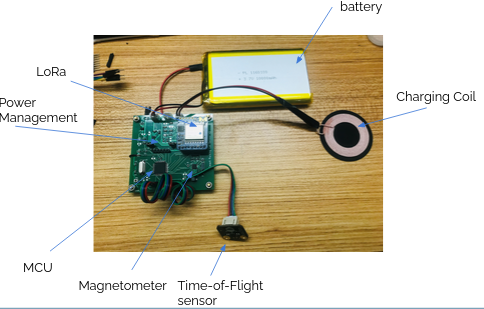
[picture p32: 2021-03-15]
demo_pics/PCBAssembly00.png

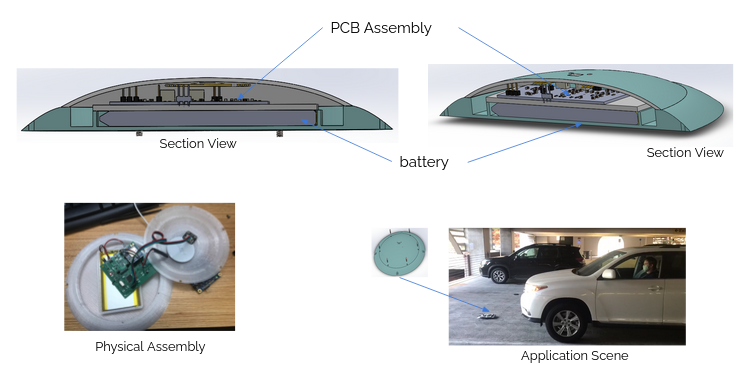
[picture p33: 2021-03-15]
demo_pics/CaseAssembly.png

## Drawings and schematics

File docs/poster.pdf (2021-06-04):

## Drivers spend too much time in parking lots trying to find an open space. We are aiming to design a smart parking

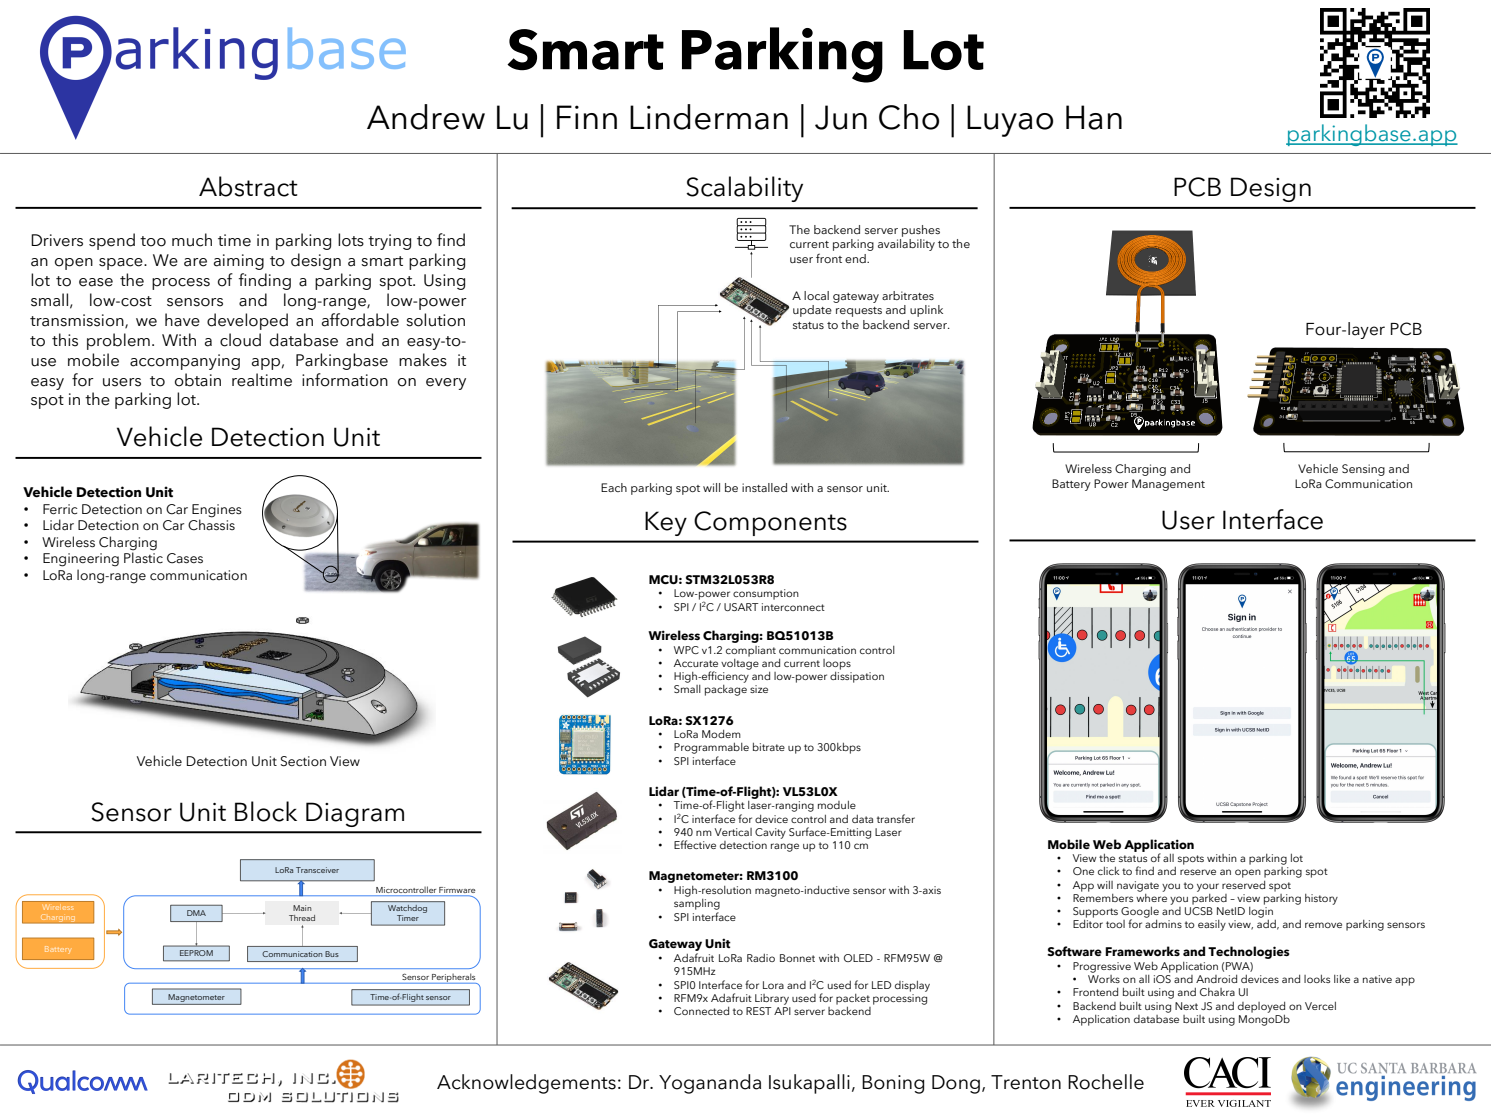
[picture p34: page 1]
parkingbase.app; Abstract; DMA; EEPROM; Communication Bus; Main Thread; Watchdog Timer; 2C / USART interconnect; PCB Design; Key Components; User Interface; Scalability; Magnetometer; Time-of-Flight sensor; LoRa Transceiver; Microcontroller Firmware; Sensor Peripherals; Wireless Charging; Battery

Smart Parking Lot

Andrew Lu | Finn Linderman | Jun Cho | Luyao Han

The backend server pushes
current parking availability to the
user front end.

lot to ease the process of finding a parking spot. Using
small, low-cost sensors and long-range, low-power
transmission, we have developed an affordable solution
to this problem. With a cloud database and an easy-to-
use mobile accompanying app, Parkingbase makes it
easy for users to obtain realtime information on every
spot in the parking lot.

A local gateway arbitrates
update requests and uplink
status to the backend server.

Four-layer PCB

Vehicle Detection Unit

Wireless Charging and
Battery Power Management

Vehicle Sensing and
LoRa Communication

Each parking spot will be installed with a sensor unit.

• Ferric Detection on Car Engines
• Lidar Detection on Car Chassis
• Wireless Charging
• Engineering Plastic Cases
• LoRa long-range communication

MCU: STM32L053R8
• Low-power consumption
• SPI / I

Wireless Charging: BQ51013B
• WPC v1.2 compliant communication control
• Accurate voltage and current loops
• High-efficiency and low-power dissipation
• Small package size

LoRa: SX1276
• LoRa Modem
• Programmable bitrate up to 300kbps
• SPI interface

Vehicle Detection Unit Section View
Sensor Unit Block Diagram

Lidar (Time-of-Flight): VL53L0X
• Time-of-Flight laser-ranging module
2C interface for device control and data transfer
• 940 nm Vertical Cavity Surface-Emitting Laser
• Effective detection range up to 110 cm

Mobile Web Application
• View the status of all spots within a parking lot
• One click to find and reserve an open parking spot
• App will navigate you to your reserved spot
• Remembers where you parked – view parking history
• Supports Google and UCSB NetID login
• Editor tool for admins to easily view, add, and remove parking sensors

Magnetometer: RM3100
• High-resolution magneto-inductive sensor with 3-axis
sampling

Gateway Unit
• Adafruit LoRa Radio Bonnet with OLED - RFM95W @
915MHz
• SPI0 Interface for Lora and I
• RFM9x Adafruit Library used for packet processing
• Connected to REST API server backend

Software Frameworks and Technologies
• Progressive Web Application (PWA)
• Works on all iOS and Android devices and looks like a native app
• Frontend built using and Chakra UI
• Backend built using Next JS and deployed on Vercel
• Application database built using MongoDb

2C used for LED display

Acknowledgements: Dr. Yogananda Isukapalli, Boning Dong, Trenton Rochelle

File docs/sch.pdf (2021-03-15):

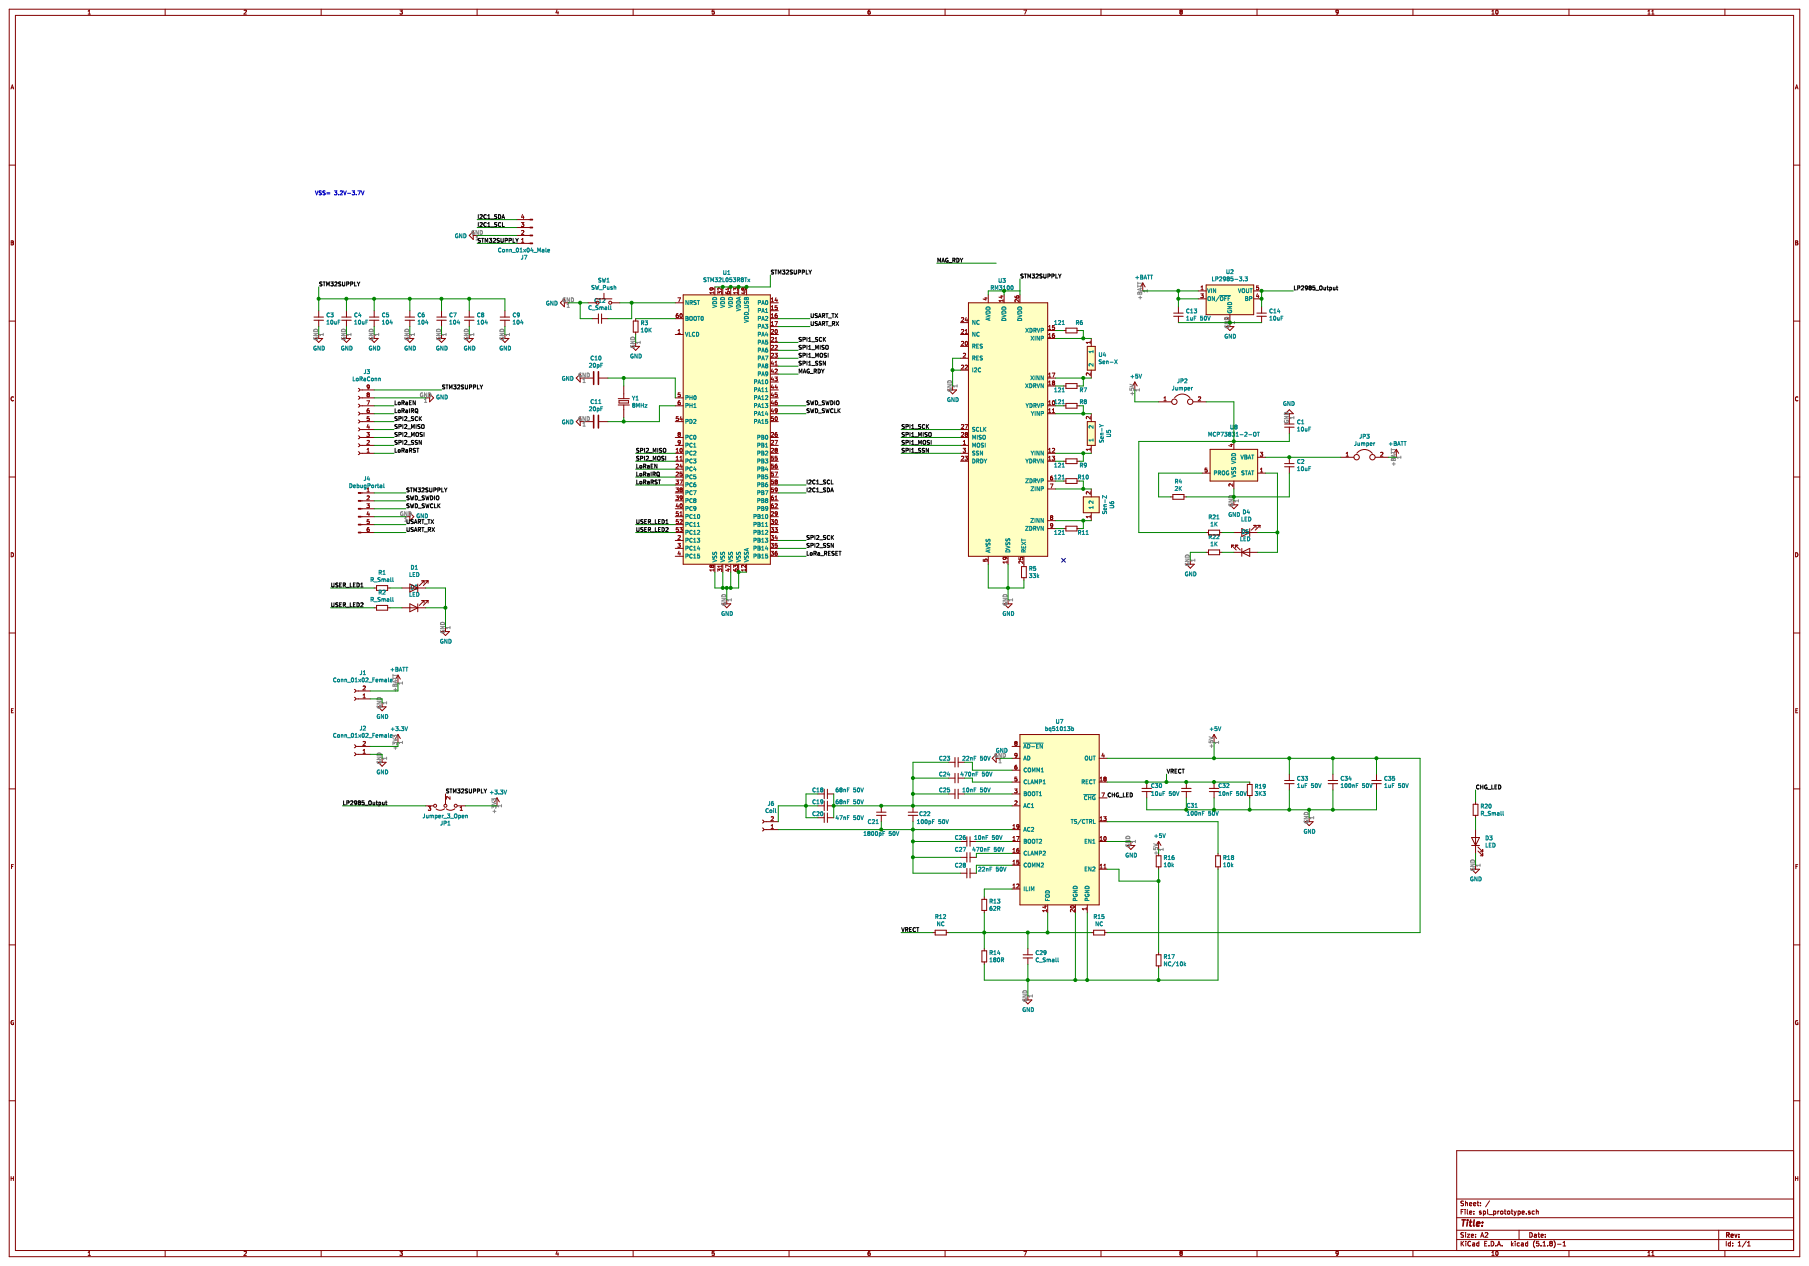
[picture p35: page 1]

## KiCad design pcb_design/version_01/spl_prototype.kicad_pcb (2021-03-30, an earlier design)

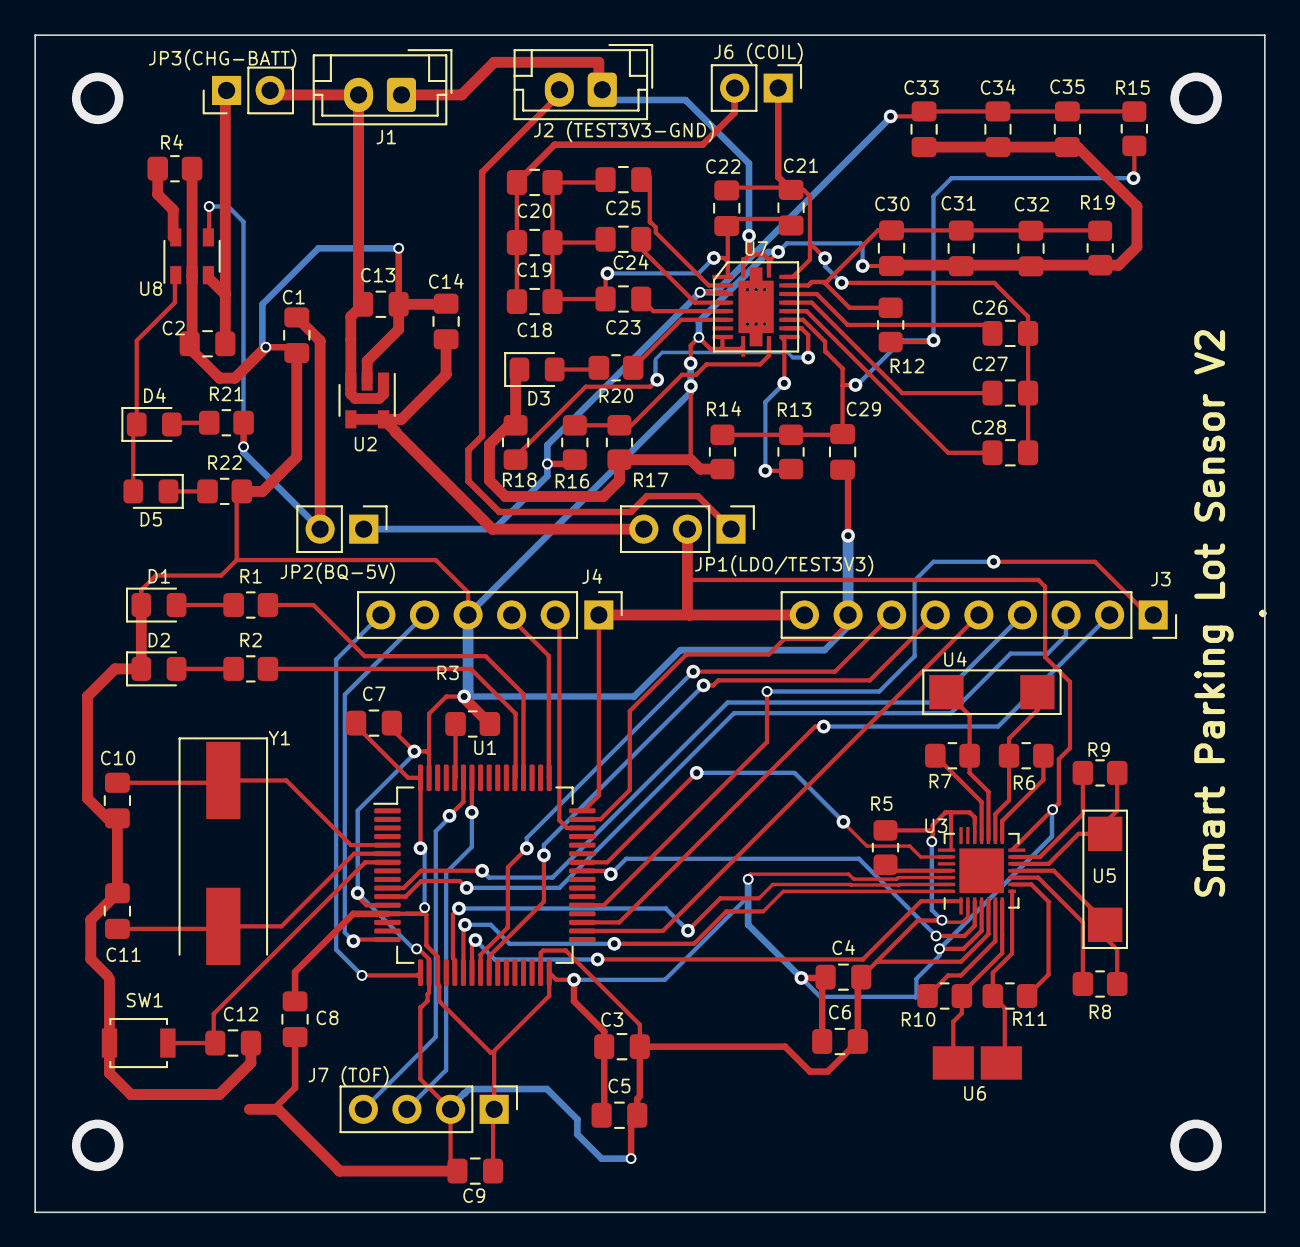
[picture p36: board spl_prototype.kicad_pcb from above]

Board: 2 copper layers, 71.6 x 68.6 mm, 78 parts (0 on the bottom side), 67 nets.

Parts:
C1, C2, C3, C4: 10uF; C_0805_2012Metric_Pad1.18x1.45mm_HandSolder
C5, C6, C7, C8, C9, C14: 104; C_0805_2012Metric_Pad1.18x1.45mm_HandSolder
C10, C11: 20pF; C_0805_2012Metric_Pad1.18x1.45mm_HandSolder
C12, C29: C_Small; C_0805_2012Metric_Pad1.18x1.45mm_HandSolder
C13, C33, C35: 1uF 50V; C_0805_2012Metric_Pad1.18x1.45mm_HandSolder
C18, C19: 68nF 50V; C_0805_2012Metric_Pad1.18x1.45mm_HandSolder
C20: 47nF 50V; C_0805_2012Metric_Pad1.18x1.45mm_HandSolder
C21: 1800pF 50V; C_0805_2012Metric_Pad1.18x1.45mm_HandSolder
C22: 100pF 50V; C_0805_2012Metric_Pad1.18x1.45mm_HandSolder
C23, C28: 22nF 50V; C_0805_2012Metric_Pad1.18x1.45mm_HandSolder
C24, C27: 470nF 50V; C_0805_2012Metric_Pad1.18x1.45mm_HandSolder
C25, C26, C32: 10nF 50V; C_0805_2012Metric_Pad1.18x1.45mm_HandSolder
C30: 10uF 50V; C_0805_2012Metric_Pad1.18x1.45mm_HandSolder
C31, C34: 100nF 50V; C_0805_2012Metric_Pad1.18x1.45mm_HandSolder
D1, D2, D3, D4, D5: LED; LED_0805_2012Metric_Pad1.15x1.40mm_HandSolder
J1, J2 (TEST3V3-GND): Conn_01x02_Female; JST_EH_B2B-EH-A_1x02_P2.50mm_Vertical
J3: LoRaConn; PinSocket_1x09_P2.54mm_Vertical
J4: DebugPortal; PinHeader_1x06_P2.54mm_Vertical
J6 (COIL): Coil; PinHeader_1x02_P2.54mm_Vertical
J7 (TOF): Conn_01x04_Male; PinHeader_1x04_P2.54mm_Vertical
JP1(LDO/TEST3V3): Jumper_3_Open; PinHeader_1x03_P2.54mm_Vertical
JP2(BQ-5V), JP3(CHG-BATT): Jumper; PinHeader_1x02_P2.54mm_Vertical
R1, R2, R20: R_Small; R_0805_2012Metric_Pad1.20x1.40mm_HandSolder
R3: 10K; R_0805_2012Metric_Pad1.20x1.40mm_HandSolder
R4: 2K; R_0805_2012Metric_Pad1.20x1.40mm_HandSolder
R5: 33k; R_0805_2012Metric_Pad1.20x1.40mm_HandSolder
R6, R7, R8, R9, R10, R11: 121; R_0805_2012Metric_Pad1.20x1.40mm_HandSolder
R12, R15: NC; R_0805_2012Metric_Pad1.20x1.40mm_HandSolder
R13: 62R; R_0805_2012Metric_Pad1.20x1.40mm_HandSolder
R14: 180R; R_0805_2012Metric_Pad1.20x1.40mm_HandSolder
R16, R18: 10k; R_0805_2012Metric_Pad1.20x1.40mm_HandSolder
R17: NC/10k; R_0805_2012Metric_Pad1.20x1.40mm_HandSolder
R19: 3K3; R_0805_2012Metric_Pad1.20x1.40mm_HandSolder
R21, R22: 1K; R_0805_2012Metric_Pad1.20x1.40mm_HandSolder
SW1: SW_Push; SW_SPST_B3U-1000P
U1: STM32L053R8Tx; LQFP-64_10x10mm_P0.5mm
U2: LP2985-3.3; SOT-23-5
U3: RM3100; QFN-28_EP_4x4_Pitch0.4mm
U4: Sen-X; RM3100_SEN_XY
U5: Sen-Y; RM3100_SEN_XY
U6: Sen-Z; RM3100_SEN_Z
U7: bq51013b; VQFN20
U8: MCP73831-2-OT; SOT-23-5
Y1: 8MHz; Crystal_SMD_HC49-SD

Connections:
+3V3: J2 (TEST3V3-GND).2, JP1(LDO/TEST3V3).1
+5V: C33.1, C34.1, C35.1, JP2(BQ-5V).1, R15.2, R16.1, U7.4
+BATT: C13.1, J1.2, JP3(CHG-BATT).2, U2.1, U2.3
/CHG_LED: R20.1, U7.7
/I2C1_SCL: J7 (TOF).3, U1.58
/I2C1_SDA: J7 (TOF).4, U1.59
/LP2985_Output: C14.1, JP1(LDO/TEST3V3).3, U2.4, U2.5
/LoRaEN: J3.7, U1.24
/LoRaIRQ: J3.6, U1.25
/LoRaRST: J3.1, U1.37
/MAG_RDY: U1.42, U3.23
/SPI1_MISO: U1.22, U3.28
/SPI1_MOSI: U1.23, U3.1
/SPI1_SCK: U1.21, U3.27
/SPI1_SSN: U1.41, U3.3
/SPI2_MISO: J3.4, U1.10
/SPI2_MOSI: J3.3, U1.11
/SPI2_SCK: J3.5, U1.34
/SPI2_SSN: J3.2, U1.35
/STM32SUPPLY: C3.1, C4.1, C5.1, C6.1, C7.1, C8.1, C9.1, J3.9, J4.1, J7 (TOF).1, JP1(LDO/TEST3V3).2, U1.13, U1.19, U1.32, U1.48, U1.64, U3.4, U3.14, U3.26
/SWD_SWCLK: J4.3, U1.49
/SWD_SWDIO: J4.2, U1.46
/USART_RX: J4.6, U1.17
/USART_TX: J4.5, U1.16
/USER_LED1: R1.2, U1.52
/USER_LED2: R2.2, U1.53
/VRECT: C30.2, C31.2, C32.2, R12.1, R19.1, U7.18
GND: C1.1, C2.2, C3.2, C4.2, C5.2, C6.2, C7.2, C8.2, C9.2, C10.2, C11.2, C12.2, C13.2, C14.2, C29.2, C30.1, C31.1, C32.1, C33.2, C34.2, C35.2, D1.1, D2.1, D3.1, J1.1, J2 (TEST3V3-GND).1, J3.8, J4.4, J7 (TOF).2, R3.2, R4.1, R5.2, R14.2, R17.2, R18.2, R19.2, R22.2, SW1.1, U1.12, U1.18, U1.31, U1.47, U1.63, U2.2, U3.2, U3.5, U3.19, U3.22, U7.1, U7.9, U7.10, U7.20, U8.2
unnamed: C1.2, JP2(BQ-5V).2, R21.2, U8.4
unnamed: C2.1, JP3(CHG-BATT).1, U8.3
unnamed: C10.1, U1.5, Y1.1
unnamed: C11.1, U1.6, Y1.2
unnamed: C12.1, SW1.2, U1.7
unnamed: C18.1, C19.1, C20.1, C21.1, C22.1, C23.2, C24.2, C25.2, U7.2
unnamed: C18.2, C19.2, C20.2, J6 (COIL).2
unnamed: C21.2, C22.2, C26.2, C27.2, C28.2, J6 (COIL).1, U7.19
unnamed: C23.1, U7.6
unnamed: C24.1, U7.5
unnamed: C25.1, U7.3
unnamed: C26.1, U7.17
unnamed: C27.1, U7.16
unnamed: C28.1, U7.15
unnamed: C29.1, R12.2, R13.2, R14.1, R15.1, U7.14
unnamed: D1.2, R1.1
unnamed: D2.2, R2.1
unnamed: D3.2, R20.2
unnamed: D4.1, D5.2, U8.1
unnamed: D4.2, R21.1
unnamed: D5.1, R22.1
unnamed: R3.1, U1.60
unnamed: R4.2, U8.5
unnamed: R5.1, U3.25
unnamed: R6.1, U3.16, U4.1
unnamed: R6.2, U3.15
unnamed: R7.1, U3.17, U4.2
unnamed: R7.2, U3.18
unnamed: R8.1, U3.11, U5.2
unnamed: R8.2, U3.10
unnamed: R9.1, U3.12, U5.1
unnamed: R9.2, U3.13
unnamed: R10.1, U3.7, U6.2
unnamed: R10.2, U3.6
unnamed: R11.1, U3.8, U6.1
unnamed: R11.2, U3.9
unnamed: R13.1, U7.12
unnamed: R16.2, R17.1, U7.11
unnamed: R18.1, U7.13

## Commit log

2021-03-30 uploaded PCB V2. Kicad
    [spl_prototype.kicad_pcb, spl_prototype.sch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]
2021-05-25 Updated sensor unit image
